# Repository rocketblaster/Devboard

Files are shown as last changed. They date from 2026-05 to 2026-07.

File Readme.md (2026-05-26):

# Development Board

## Description
This is a 47x35mm development board PCB made with a bare bones ESP32-C3. It can support wireless connections which is useful. It contanis three pin headers, with one containing power supply gpio. The other one is GPIO only and lastly the 2 pins are for TXD and RXD. Uses USB-C to get power. Boot switch and reset switch helps to activate anything using the chip. Chip enable can be connected via pins.

There's a red power LED near USB-C. Blue and green located on top for testing LED on top for testing LED. The case features pinout labels.

## Case

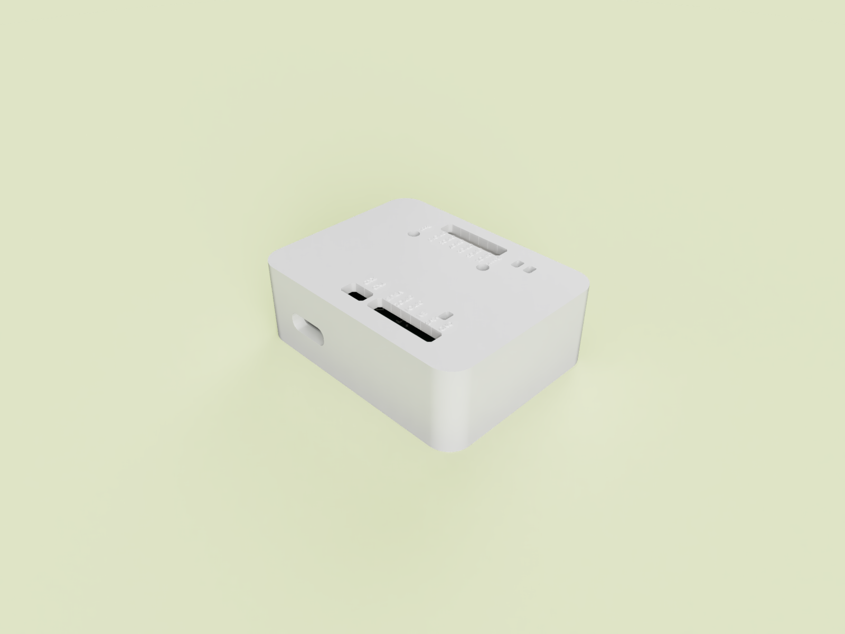
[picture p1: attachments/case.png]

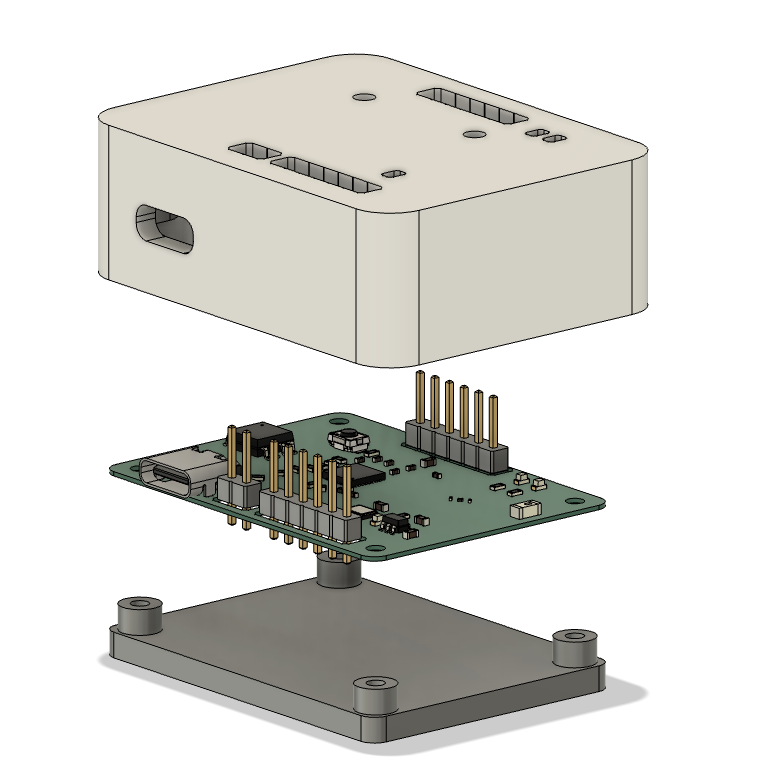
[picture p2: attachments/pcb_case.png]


## Demo Case

[3D case demo link](https://a360.co/3RtKpME)

## KiCanvas

[Demo Link](https://kicanvas.org/?repo=https%3A%2F%2Fgithub.com%2Frocketblaster%2FDevboard%2Ftree%2Fmain%2Fsrc%2Fkicad)

## Schematic

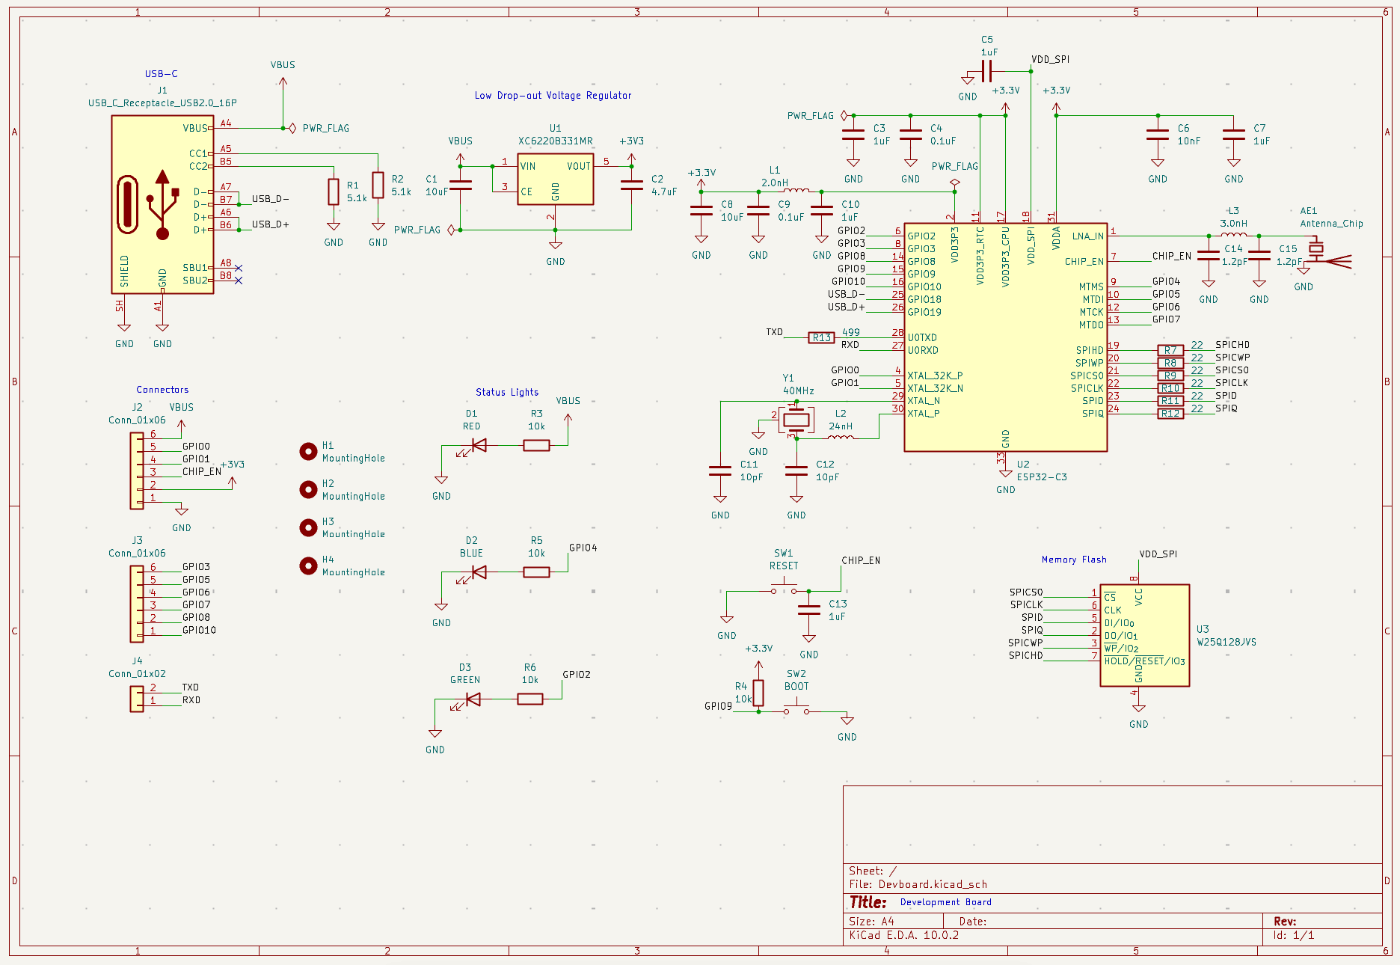
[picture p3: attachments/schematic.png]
Schematic


## PCB

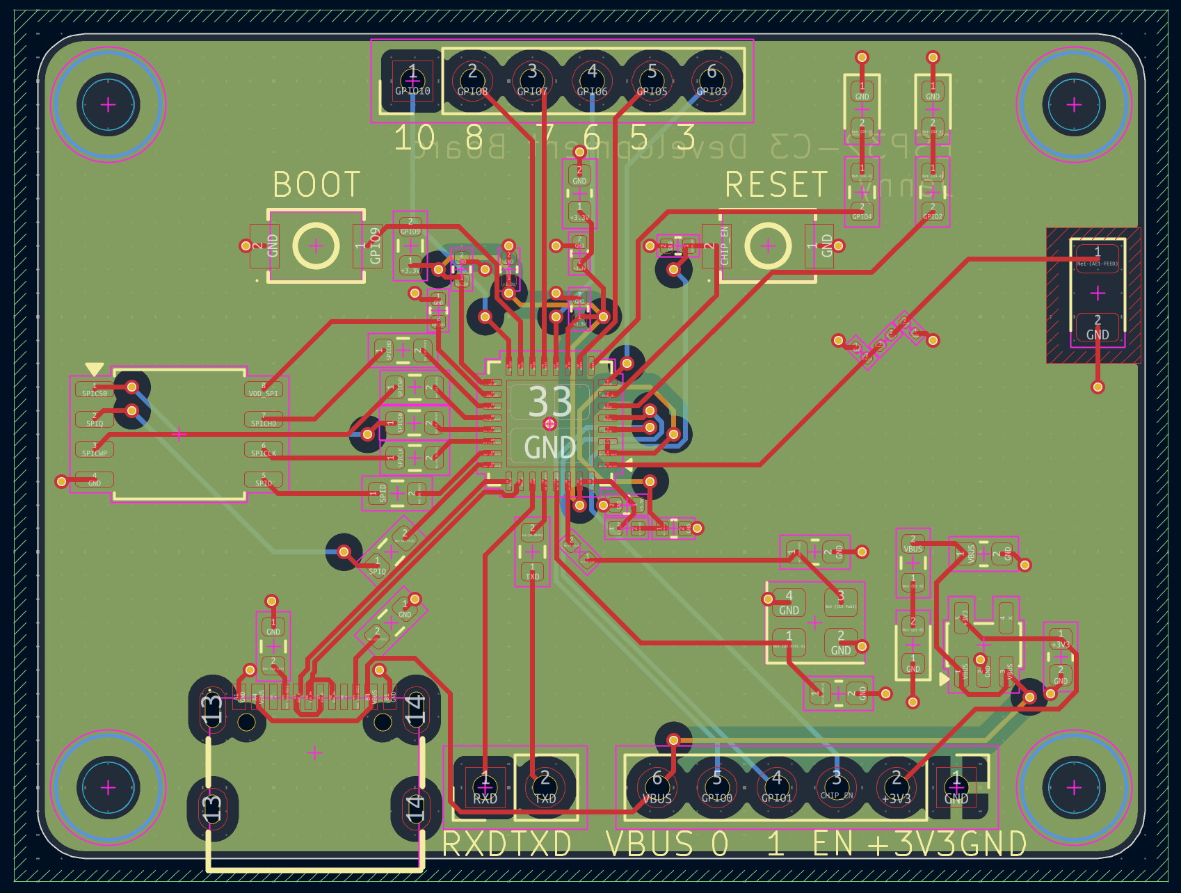
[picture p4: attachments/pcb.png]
PCB


## Render

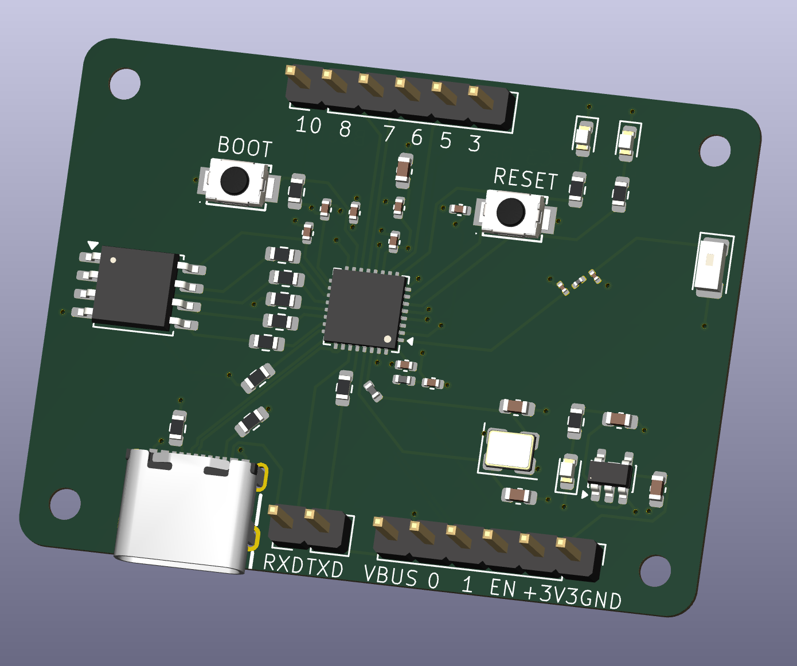
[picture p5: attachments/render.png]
Render


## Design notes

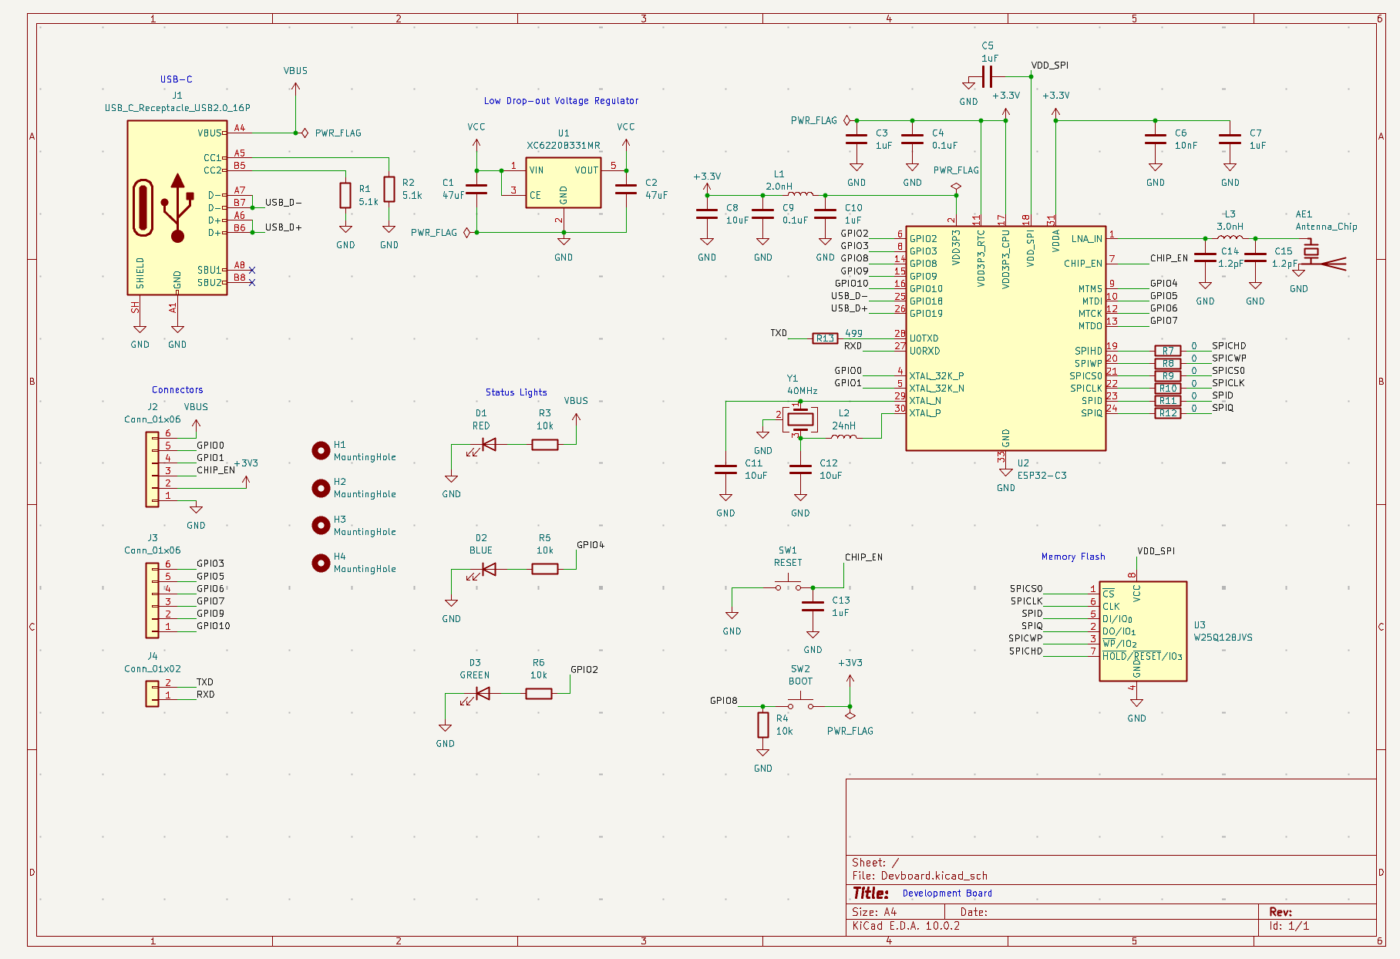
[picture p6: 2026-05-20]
attachments/schematic-v1.png

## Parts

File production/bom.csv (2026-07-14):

Designator | Footprint | Quantity | Value | LCSC Part #
AE1 | Johanson_2450AT18x100 | 1 | Antenna_Chip | C17192881
C1, C8 | 0603 | 2 | 10uF | C85713
C10, C13, C3, C5, C7 | 0402 | 5 | 1uF | C22399609
C11, C12 | 0603 | 2 | 10pF | C1634
C14, C15 | 0201 | 2 | 1.2pF | C21610742
C2 | 0603 | 1 | 4.7uF | C6119855
C4, C9 | 0402 | 2 | 0.1uF | C53084459
C6 | 0402 | 1 | 10nF | C60133
D1 | 0603 | 1 | RED | C19171390
D2 | 0603 | 1 | BLUE | C965807
D3 | 0603 | 1 | GREEN | C19273151
J1 | USB-C-SMD_TYPE-C-16PIN-2MD-073 | 1 | USB_C_Receptacle_USB2.0_16P | C2765186
L1 | 0402 | 1 | 2.0nH | C76769
L2 | 0402 | 1 | 24nH | C1012734
L3 | 0201 | 1 | 3.0nH | C2041469
R1, R2 | 0603 | 2 | 5.1k | C2907044
R10, R11, R12, R7, R8, R9 | 0603 | 6 | 22 | C2907129
R13 | 0603 | 1 | 499 | C23065
R3, R4, R5, R6 | 0603 | 4 | 10k | C2930027
SW1 | SW-SMD_L3.9-W3.0-P4.45 | 1 | RESET | C720477
SW2 | SW-SMD_L3.9-W3.0-P4.45 | 1 | BOOT | C720477
U1 | SOT-23-5 | 1 | XC6220B331MR | C86534
U2 | QFN-32-1EP_5x5mm_P0.5mm_EP3.7x3.7mm | 1 | ESP32-C3 | C2838500
U3 | SOIC-8_5.3x5.3mm_P1.27mm | 1 | W25Q128JVS | C179171
Y1 | Crystal_SMD_3225-4Pin_3.2x2.5mm | 1 | 40MHz | C379787

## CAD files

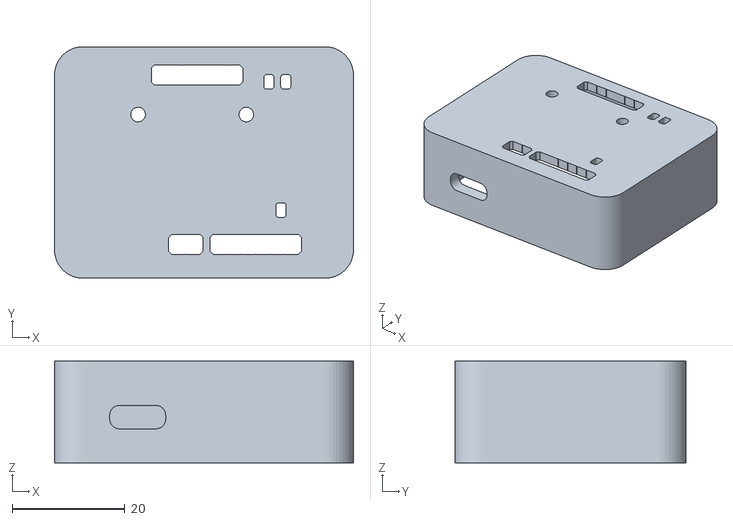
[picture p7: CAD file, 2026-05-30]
production/case_top.stl
53.0 x 41.0 x 18.0

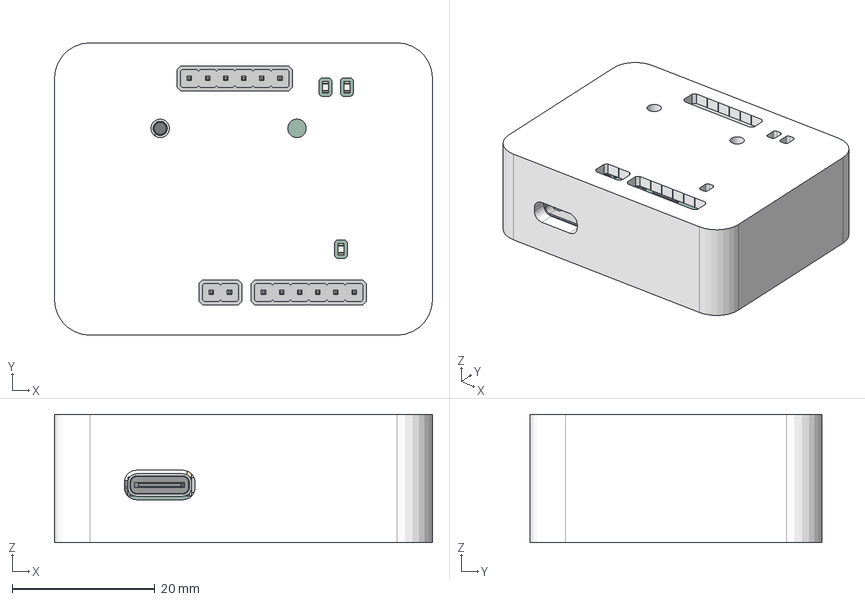
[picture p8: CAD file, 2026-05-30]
src/case.step
53.0 x 41.0 x 18.0 mm
R_0603_1608Metric_1 x 13
C_0402_1005Metric_1 x 8
L_0201_0603Metric_1
C_0603_1608Metric_1 x 5
QFN-32-1EP_5x5mm_P0.5mm_EP3.7x3.7mm_1
PinHeader_1x06_P254mm_Vertical x 2
L_0402_1005Metric_1 x 2
C_0201_0603Metric_1 x 2
USB-C-SMD_TYPE-C-6PIN-2MD-073_1
LED_0603_1608Metric_1 x 3
SOT-23-5_1
SOIC-8_5.3x5.3mm_P1.27mm_1
Crystal_SMD_3225-4Pin_3.2x2.5mm_1
PinHeader_1x02_P254mm_Vertical
Johanson_2450AT18x100_1
SW-SMD_L3.9-W2.9-H2.0-LS4.8_1
Devboard_PCB

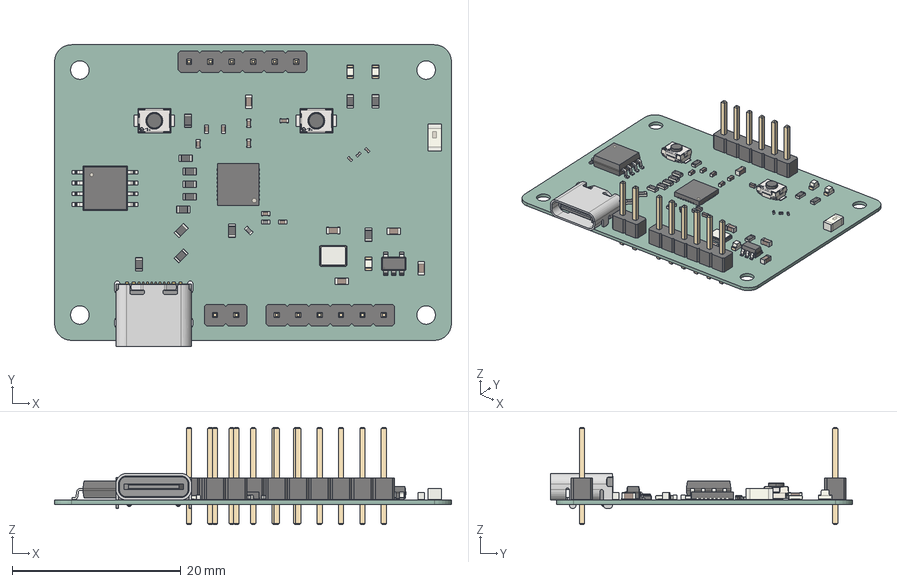
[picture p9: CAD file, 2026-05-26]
src/kicad/3D.step
47.0 x 35.7 x 11.5 mm
R_0603_1608Metric x 13
C_0402_1005Metric x 8
L_0201_0603Metric
C_0603_1608Metric x 5
QFN-32-1EP_5x5mm_P0.5mm_EP3.7x3.7mm
PinHeader_1x06_P254mm_Vertical x 2
L_0402_1005Metric x 2
C_0201_0603Metric x 2
USB-C-SMD_TYPE-C-6PIN-2MD-073
LED_0603_1608Metric x 3
SOT-23-5
SOIC-8_5.3x5.3mm_P1.27mm
Crystal_SMD_3225-4Pin_3.2x2.5mm
PinHeader_1x02_P254mm_Vertical
Johanson_2450AT18x100
SW-SMD_L3.9-W2.9-H2.0-LS4.8 x 2
Devboard_PCB

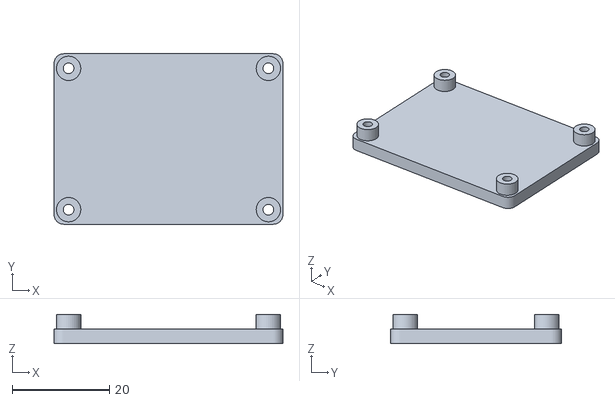
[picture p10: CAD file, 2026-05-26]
production/case_bottom.stl
47.0 x 35.0 x 6.00

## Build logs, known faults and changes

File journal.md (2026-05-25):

## May 10, 2026
I wonder what dev boards are useful for. What problems do I want to solve? Some features I would add is to make my development board aesthetically pleasing. For easier connectivity I'm going to add USB connectors. Since my computer is primarily USB-C I will use USB-C. Also usb-c is just easier in general. I need a one way usb-c with one way anything. With the intent of adding a case too eventually. I want to protect my devboard in someway. But that means I need to leave slots option for pinouts if I do add them. I think I will go with RP2040 for general purpose. But I need to make it unique in some way. It doesn't have wifi support though. Some applications I want to use my development board might include wifi, for example temperature readings or a wifi-powered clock from the cloud. I think I'll stick with the ESP32.

This ESP32 has an internal 8 MHz oscillator as I read through the datasheet for the ESP32 chip. It does not need an 8 MHz crystal oscillator then. however the addition of external crystal clock sources are typical 160 MHz. so I'm adding a 160 MHz crysal clock source. I picked esp32-d0wd-v3.

I am finding the external crystal clock oscillator I found this one [here](https://www.lcsc.com/product-detail/C43086214.html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)

I think this is unusually a high frequency for crystal oscillator though. I am going to recheck. Besides there's not a lot of stock. Ok I rechecked and it is crystal 40 MHz for wifi or bluetooth. I found another one. It is called [YXC Crystal Oscillators OW2EL89CENUXK7YLC-40M](https://www.lcsc.com/product-detail/C48888233.html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) A 4 pin crystal

Now i need a linear regulator between power and mcu which is ESP32. Maximum operating voltage is 3.3v. USB-C supports 5v. I am going from 5v to 3.3v. Uh I'll pick the XC6206 or related because it supports up to specific volts and I want a USB-C connector. There's other manufacturers but this part has more in stock, so more popular. [MSKSEMI XC6206P332MR-MS](https://www.lcsc.com/product-detail/C5252899.html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)

Ok I forgot about the current limits. I wonder if my ESP32 model needs to handle specific levels of current. I went back to power supply and it says

"The operating voltage of ESP32 ranges from 2.3 V to 3.6 V. When using a single-power supply, the
recommended voltage of the power supply is 3.3 V, and its recommended output current is 500 mA or
more."

I need an output current of 500mA or more on ESP32. The previously mentioned LDO is not compatible most likely. I found this one and I'm going to read the datasheet. [TDSEMIC XC6220B331MR](https://www.lcsc.com/product-detail/C22466451.html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)

It can support up to output of 300mA. For ESP32-C3 the current consumption in active mode for RF is peak 335 mA.

There are too many ESP32 models. Seems I'm looking for MCU specfically. I changed my mind. I pick the ESP32-C3 for wifi compatibility. I'm not intent to make a radio or anything. There is a specific data sheet so I will read it.

I found the hardware design guide. It says the power regulation be no less than 500 mA. This model I found works after some recommendations online. [TECH PUBLIC XC6220B301MR](https://www.lcsc.com/product-detail/C23378035.html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) I like that it supports up to 900mA and 6v.

### Time Spent: 2 hr

## May 11, 2026

So the LDO I want does not have a footprint in the kicad library. No worries, I found a better alternative! I'm going to use the [XC6220B331MR-G](https://jlcpcb.com/partdetail/TorexSemicon-XC6220B331MRG/C86534) because it can support up to 1000mA! That's more than what I need but you never know. Just in case. I'm going to import this into the KiCad library.

I'm going to add a crystal somewhere too. It seems the one I picked contains 4 pinouts. So I will import a symbol with 4 pins as crystal. Actually it's a 3 pin because one of the pin is a no connect. Also I am not sure where the mcu pinout is so I'm reading the diagram right now.

The document mentions about an analog pin called XTAL_N and XTAL_P which is connected to "external clock input/output connected to the chip's crystal or oscillator. P/N means differential clock positive negative"

And XTAL_32K_N and XTAL_32K_P for a 32kHz external clock input or output connected to ESP32-C3's crystal or oscillator.

I think I'm not going for the 32kHZ external clock because I have a 40 MHz crystal. Connecting it to XTAL_N and XTAL_P.

LDO pin I find out
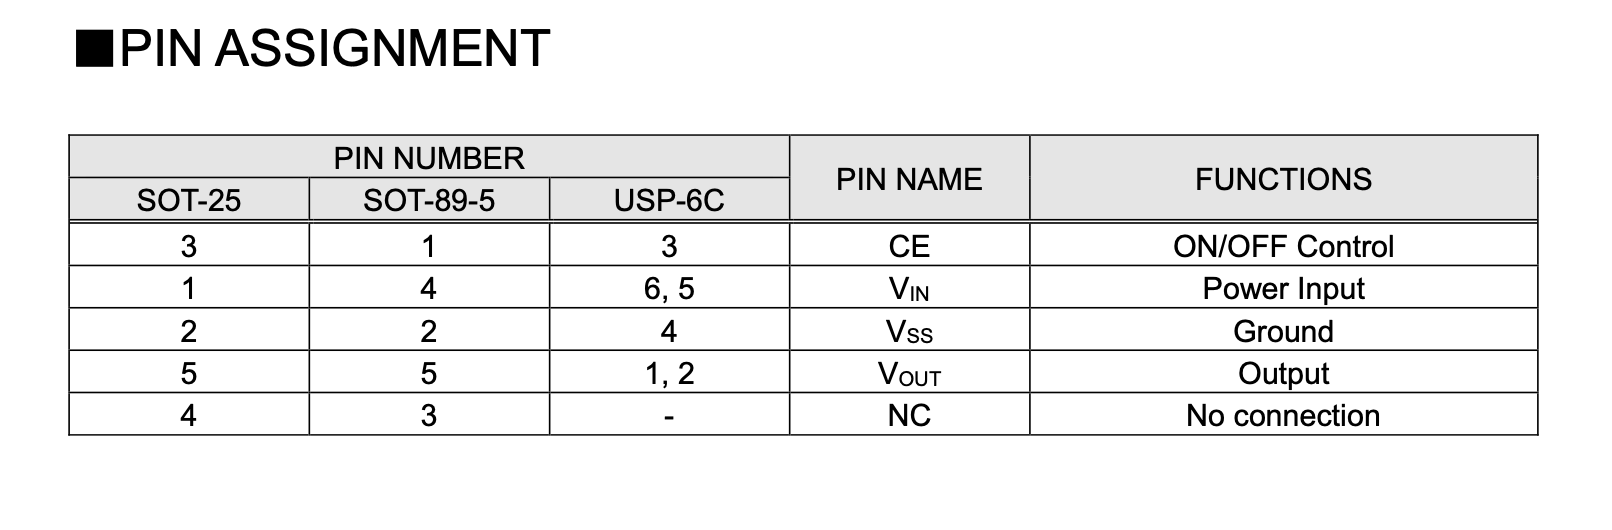
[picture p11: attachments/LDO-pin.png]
LDO pin


I don't know what CE and Vout goes to so I'll come back later.

Uh oh I read through the XC6220 and it's PCBA only. Come back later. Anyways I since the USB-C says VBUS I changed it to VBUS. I also have CC1 and CC2 but wired it to 5.1k pullup resistors as usual

My LDO needs capacitors to store some energy. I checked the data sheet and it says
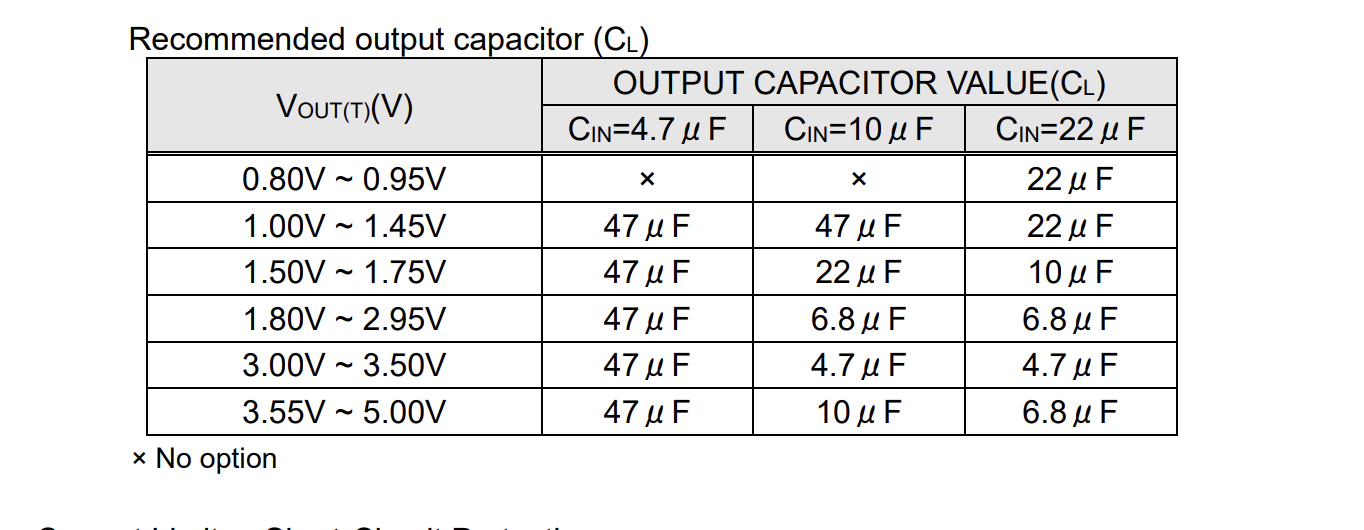
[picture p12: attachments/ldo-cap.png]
LDO cap


Maybe 47uF? Since it says voltage out. So I'm picking a 47uF capacitor then. But where does this go? After some researching, it seems my capacitor size depends on the crystal I have... I can 47 from what's recommended. It's hard to read. Datasheet wants a capacitor between VIN and VSS (ground). Same for VOut and VSS. Will also add somne net labels to the USB-C. I still have a CE pin left floating. It's an input pin. I will connect to Vin to keep it constantly on so it is open.

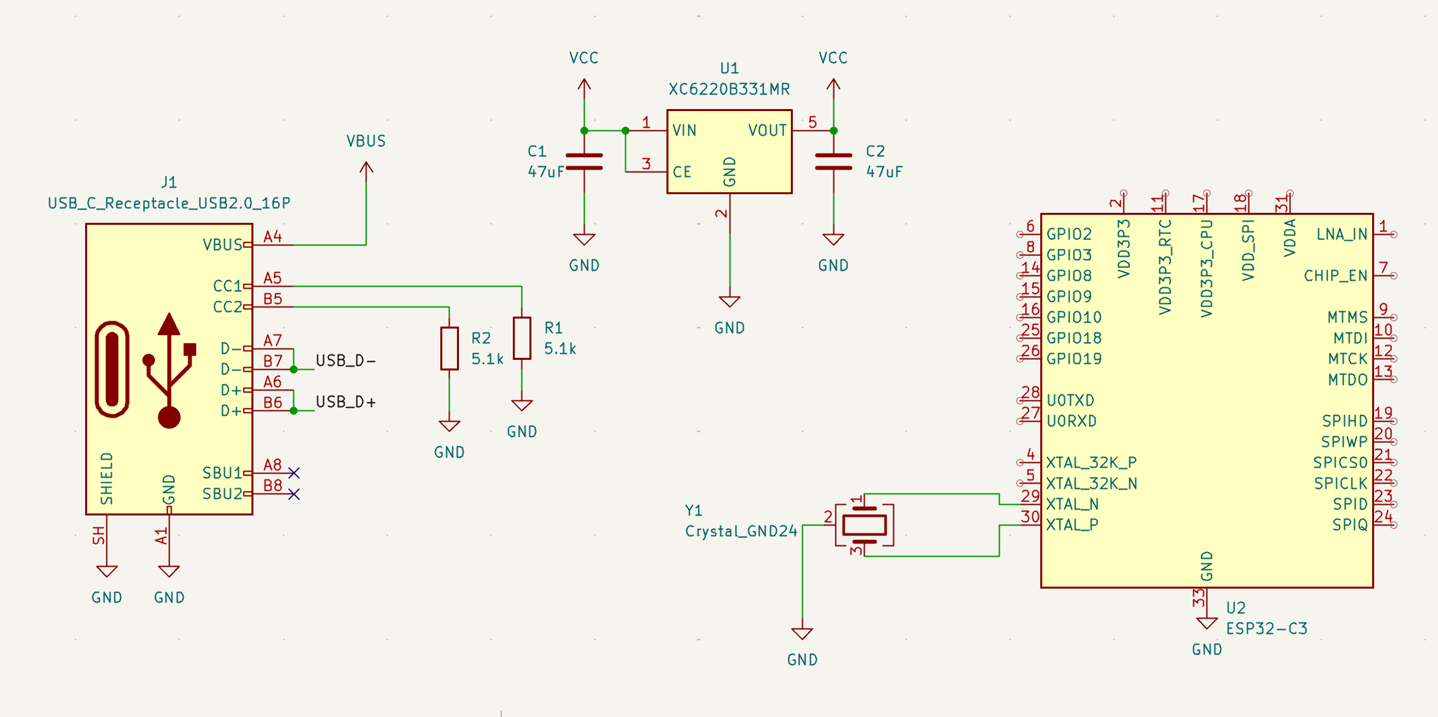
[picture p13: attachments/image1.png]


I'm moving on to the MCU. I have a lot of pins that start with V. Let's start by reading the datasheet and seeing what it says.

### Time Spent: 1 Hour

## May 12, 2026

Alright where I left off on was trying to wire up the VDD pinouts. So I'm going to read the datasheet.

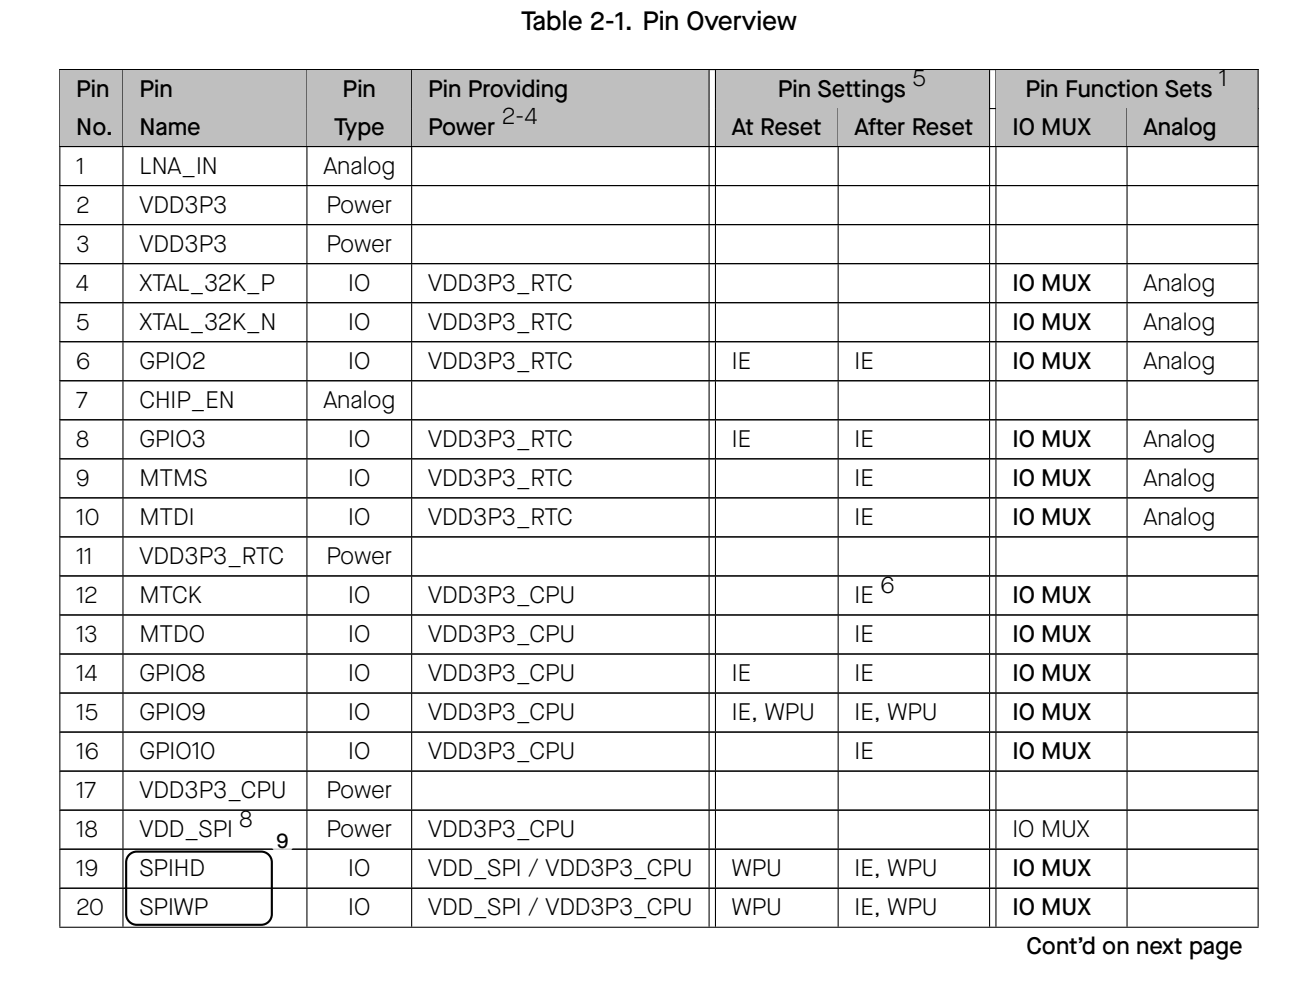
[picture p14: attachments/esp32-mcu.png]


I wonder if I need any capacitors. It is unclear in the datasheet but maybe it is because i am not reading deep enough. But I guess they're all connected to capacitors which lead to ground. I'm following the hardware design schematic guide from the docs. I am told to connect 0.1uF or 100nF capacitors.

"When using a single power supply, the recommended power supply voltage is 3.3 V and the output current is no less than 500 mA.

It is suggested to add an ESD protection diode and at least 10 μF capacitor at the power entrance."

I am going to add a 10uF capacitor at the power entrance. I don't know what to do with VDD_SPI, a digital pin. It seems it wants to connect a 1uF to ground according to the datasheet. I'll just follow it. Then I rename my designator labels so the numbers read left to right.

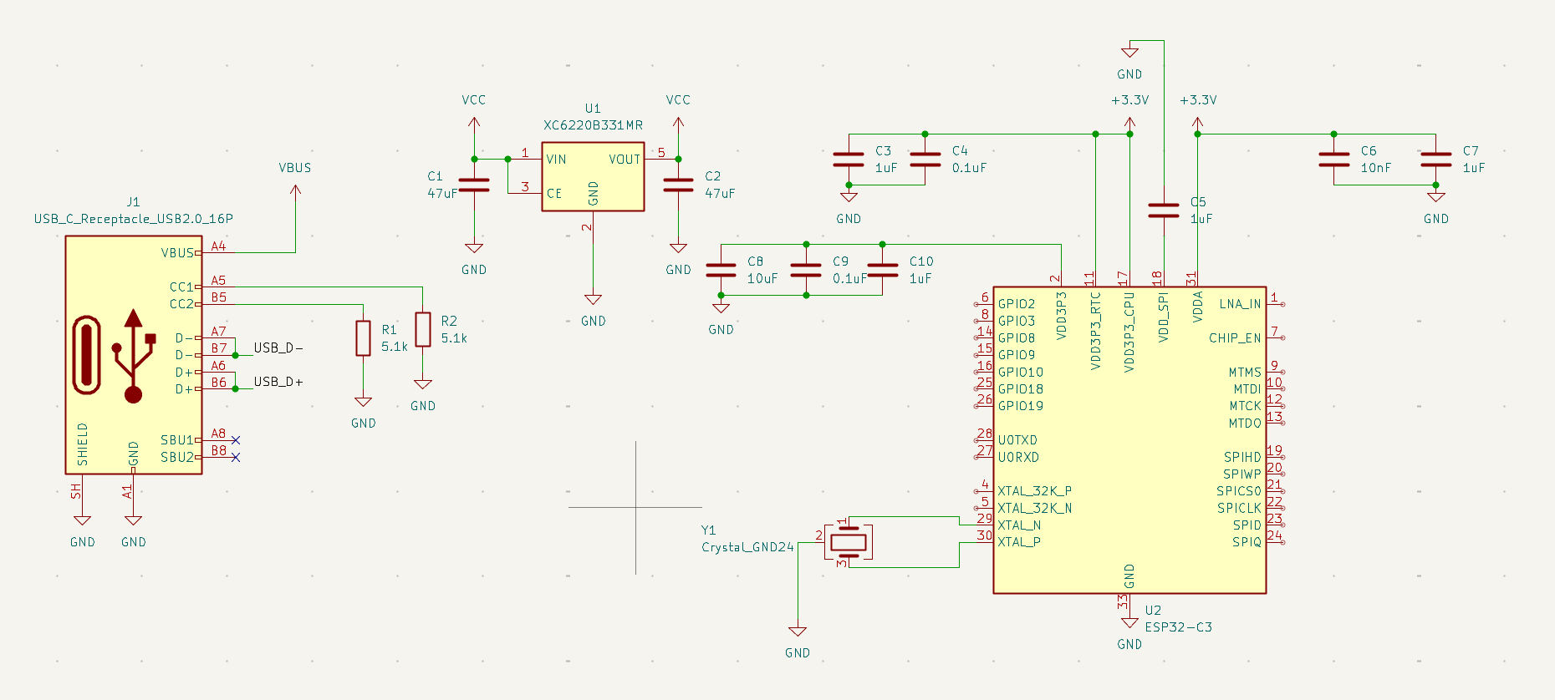
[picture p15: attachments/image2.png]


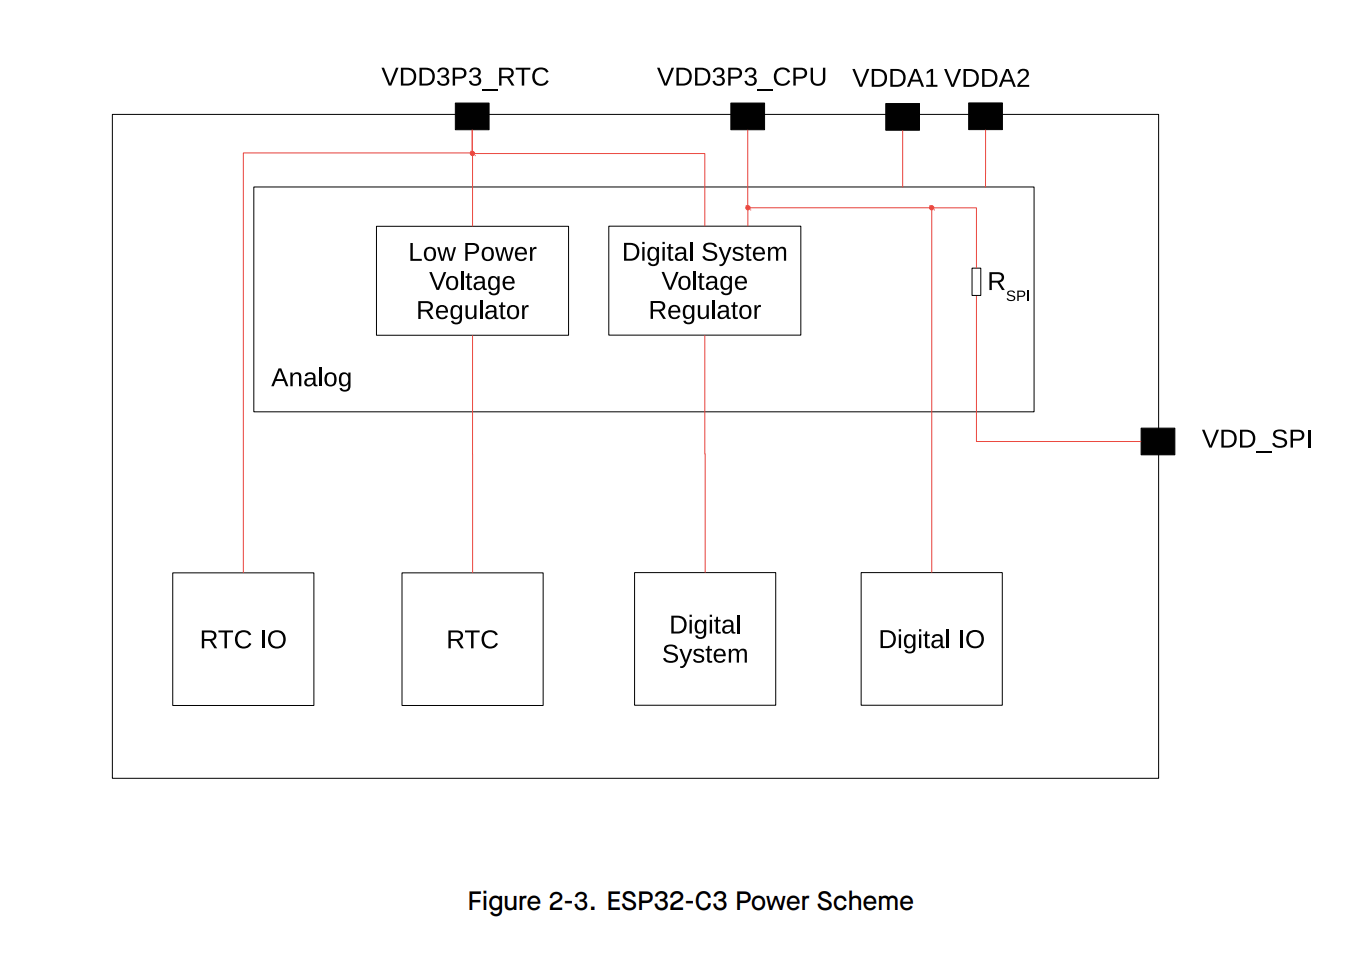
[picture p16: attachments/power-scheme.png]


Oh also I found a better crystal. The one I originally found did not support 10.0ppm but this one does as it is also 40MHz. It is called [YXC Crystal Oscillators XL2EL89CPI-111YLC-40M](https://www.lcsc.com/product-detail/C5444549.html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)

Its load capacitance is 10uF or 20uF
Maybe I will try a 10uF.

C = 2(10-5) C

Just in case, and I end up with 10uF capacitors each. Next, some research of the docs told me to connect the USB D and N pairs to GPIO 18 and 19. I still need to figure out how the decoupling capacitors works... Moreso of its organization. i'll figure the rest of the pinouts in the next day.

### Time Spent: 1 Hr

## May 15, 2026

I wonder what I should add to my development board. I'm going to creaate net labels for the rest of my schematic. The ESP32-C3 has a couple of switches, I wonder what it does. So I'll add switches, status lights and connectors. To make it different from my guided tutorial, I will change the shape and silkscreen slightly.

GPIO is programmable pin outputs. This means I could program the ESP32 and change GPIO1 to be the swtich button or something. So any GPIO pin can be a feature I can add on the board. But there are specific pins as said here

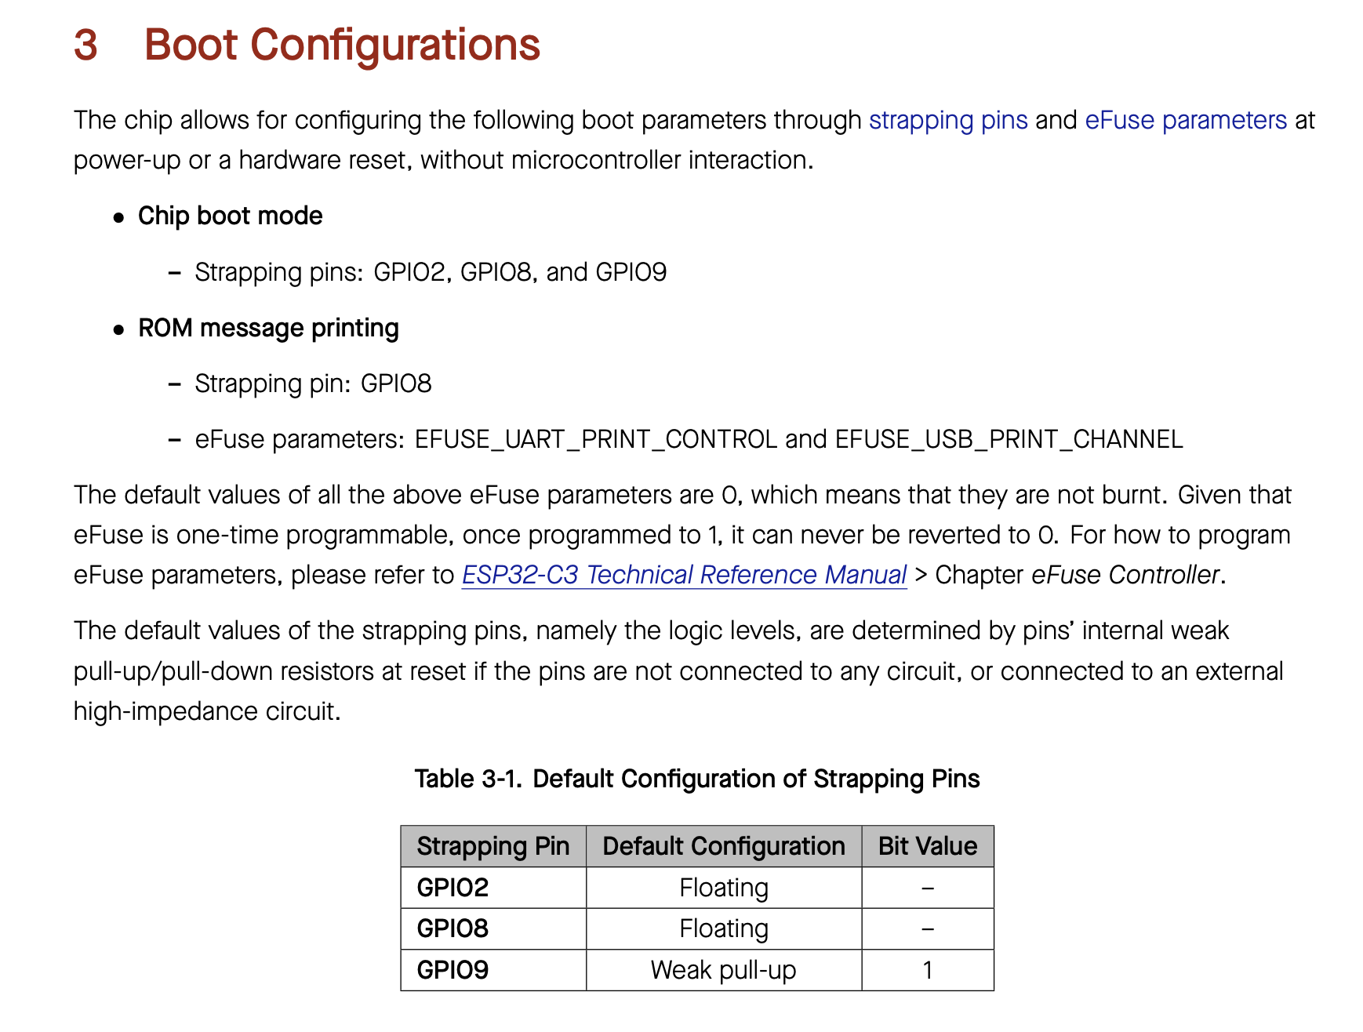
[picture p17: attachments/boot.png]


Boot needs a weak pull up resistor so I'm adding 10k ohm. For reset I'm going to add a capacitor of 1uF just to be safe. I am going to create net labels for UORXD and UOTXD. They stand for Receiver and Transmitter respectively. Yeah I'm not sure what to connect it to. For LN_IN that is a radio. I don't have a use so I'll just give it a net label. Maybe I will try to termiante it. No it goes to an antenna. I will add one. I am following the schematic diagram right now. The SPI pins are like flash. I'm adding net labels because the resistors make it look unorganized.

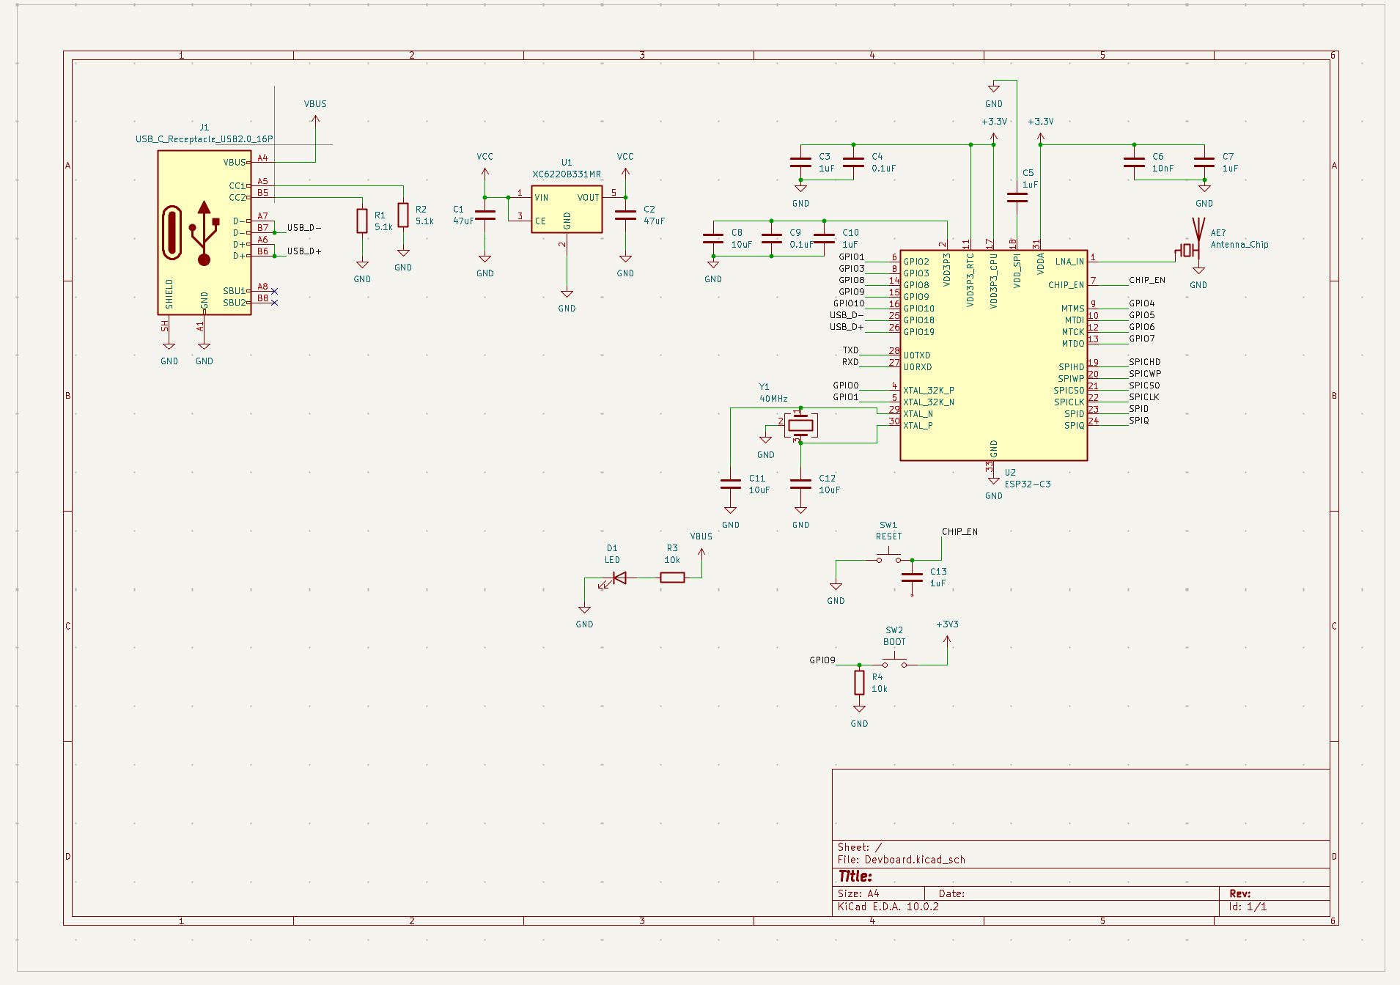
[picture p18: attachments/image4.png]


Seems like CHIP_EN is some sort of reset pin. This function of the pin is "High: on, enables the chip (powered up).
Low: off, disables the chip (powered down).
Note: Do not leave the CHIP_EN pin floating"

Some sort of power pin I suppose. I wonder if I need multiple status lights. I'll do two, since this is a small LED. The configuration I have for the LED seems unusual, so I will change it. I will leave one connected to VBUS as an indicator of it being turned on. Maybe one for blink effect too and it'll be blue. It'll be connected to a GPIO pin, wonder which one is open. If space allows, I'll add a green one! I connected the LED to GPIO8.

I noticed a flash when referencing the hardware design guide. I am powering it through USB-C so i dont think I need a flash. I'll still add it just in case. This particular part I picked was from research and it supports 128 something. I'll probably use that much lol

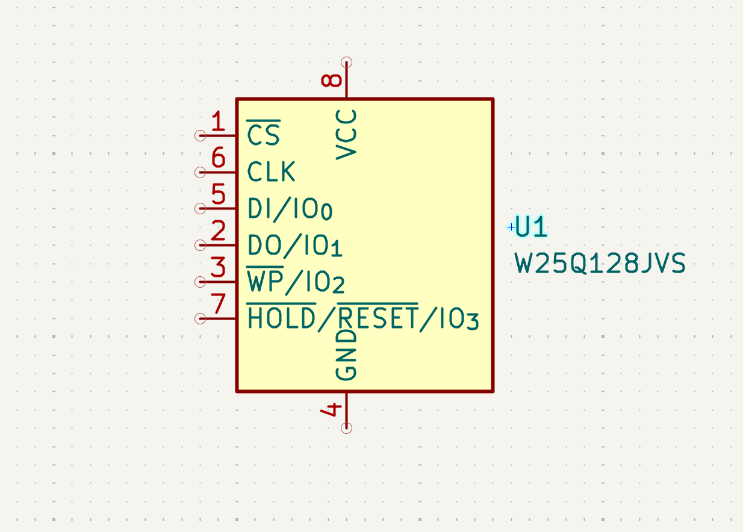
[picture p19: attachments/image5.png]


I'm removing the VDD_SPI whatever I put on there. Stil adding a capacitor to stablzie signals. Design gudie says 0 ohms, but another person put 100 on theirs. I'll probably do 0 ohm for mine because it is flexible. ugh but schematic gets crowded. Well I figured it out, I place it real close on the wire lines.

Now I need to move on to whatever's left for the schematic. How many connector pins do I want on my development board. How many pins do I have to connect? Would I put all my pins to one side or on both? Doing male headers because they're more durable and stack some jumpers on top too.

I guess I will add inductors because I cannot omit them as a bare bones chip. The values for RF Antenna is too be decided by the actual PCB traces, and the crystal I must calculate. I think 24nH is an ok value for inductor.

Still thinking about the connectors. I think I have GPIO0, GPIO1, GPIO10, GPIO4, GPIO5, GPIO6, GPIO7, TXD and RXD open. I need to include a place for 3v3 and GND as well. So that's about 9 slots plus 2 more which is 11. Maybe I'll add one more option for VBUS as well. I know there is 5v option but it needs to go downscale in volts... I guess I'll do a lopsided amount of connectors then. GPIO8, GPIO3, GPIO3 are used by the diodes. A symmetrical pattern. Oh! also for boot and reset pins too. Added those! Now it fits.

Wooo here's the schematic so far! I did a lot of organization mostly though. Waiting on specific values for PCB.

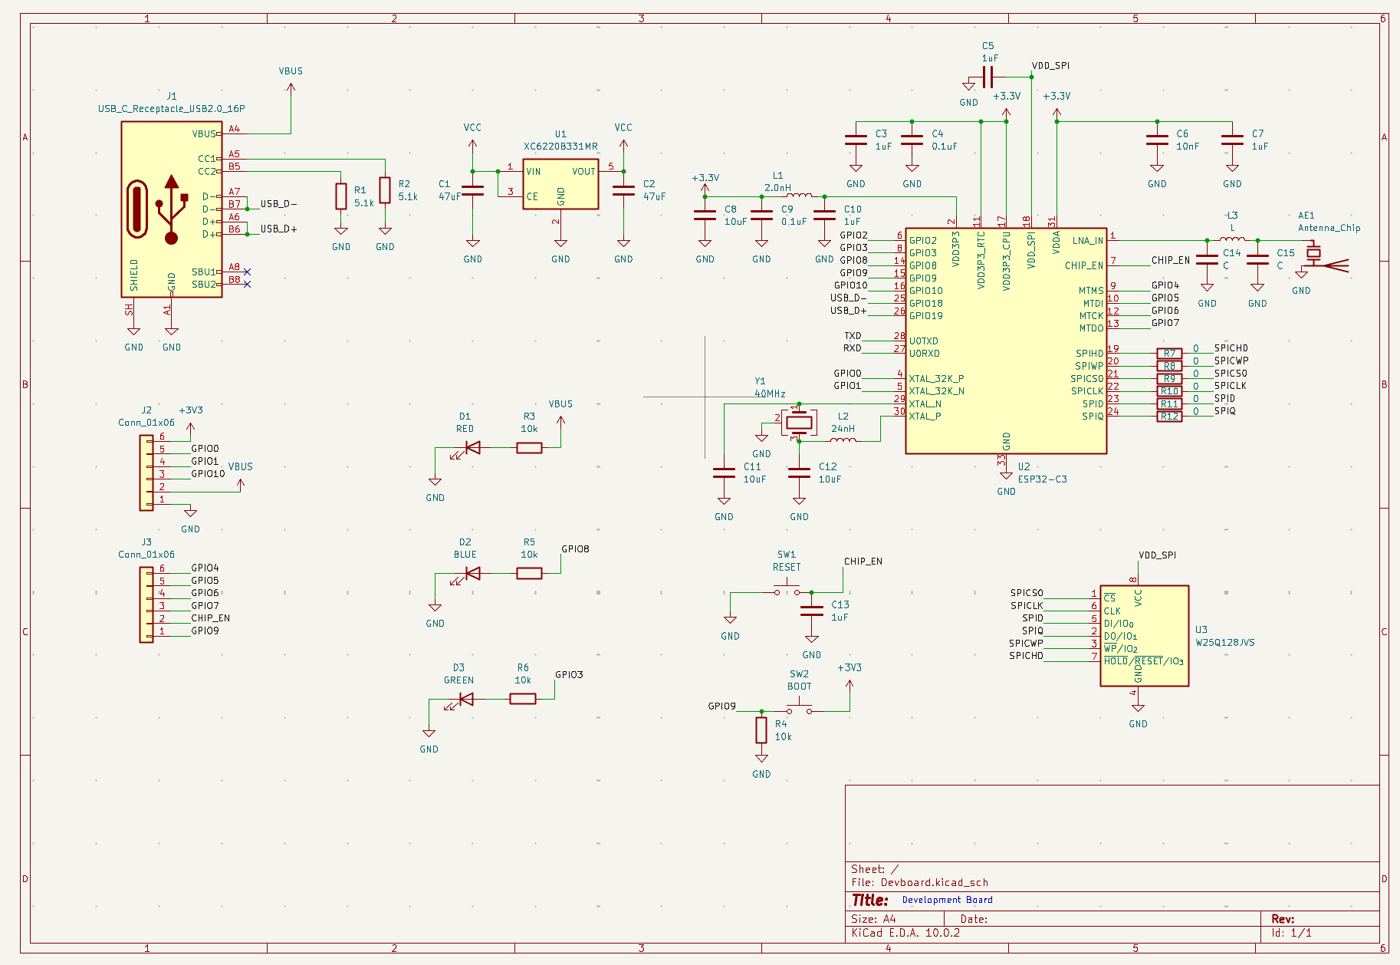
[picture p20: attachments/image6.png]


### Time Spent: 2 Hours

## May 16, 2026

I am getting to work by adding power flags. I wonder what shape my PCB should be. Why does my GHND have no input power pin. There seems to be 15 open total pins but I only have 12 at the moment. Adding one more set of connectors. Just want one power source. Then I want four mounting holes. Now I need to assign footprints. I'm going with 0603 footprints because they're simpler to solder. For RF_Antenna footprint I searched it up and it says there are many types. I'm thinking of going with a ceramic antenna since my module may be small. But I'll check the docs just in case. Probably a Johansen connector chip. For mounting holes I'm going with m2 screws because they're most accessible and in between. I need to transfer footprints over.

Spent forever trying to import the easy eda USB-C aghh. figured it out by running python script path and command. Assigned usual footprints. Not sure for mounting holes, buttons and the inductors. I guess I will go with the usual footprint for a button. It looks like 6x6mm is the standard but is not in KiCad by default. I'll use 0201 or 0603 for the inductors. I'm going to use the part number C720477.
Okay i got all of my footprints besides the mounting holes lol.

### Time Spent: ~1 Hour

## May 17, 2026

Adding mounting hole footprint finally. I import them all into the PCB. Now I create a 100mm by 100mm square. Well it has to be under. I'll try a rectangular shape and experiment with board outlines. Mostly filmed on lapse. Need some capacitors to be close together. Also I think it is best to hide silkscreen... Dev boards dont really need silkscreen labels. I have a feeling I want to swap GPIO 10 and CHIP_EN, and swap 3v3 and VBUS because of overlapping ratlines. Ugh I should've picked pins that are next too each other. I'm switching out GPIO8 for something else. Switch to GPIO9 with the boot switch. Then GPIO9 I will swap for... GPIO4 works. Doing a lot of swapping and making sure there aren't duplicates. Not sure for this extra pin connector... I have an extra slot.

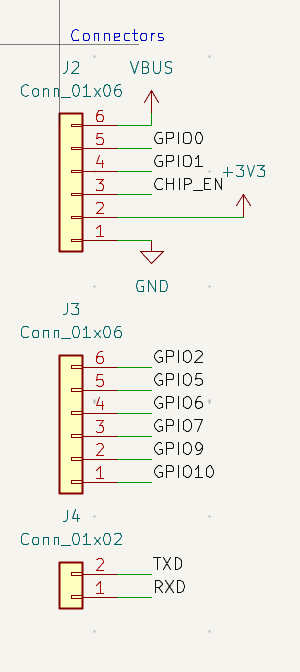
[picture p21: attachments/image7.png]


Probably will leave an extra anyways. For the memory flash I think vias are my only option. Perhaps I should go for a 4 layer board. I'll read through the design guide. Forgot to give UATXD a resistor! I need to place my resistors close to the ESP32-C3 for the flash. Definetely need vias and they're ok! GPIO pins last.

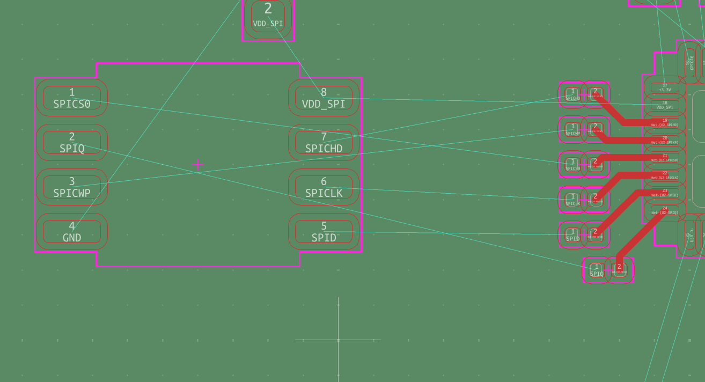
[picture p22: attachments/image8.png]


My crystal footprint is giant. The correct package is SMD3225. I'm routing all my power supply on the third layer! With some exceptions. I need to keep the RF and Crystal clean of anything underneath as well.

had to swap some values too liek GPIO because of the ratlines on the schematic.

I hate how I have so many vias. Cant do anything about it. AAAAA And my traces are all weirdly long. I just need to get rid of the silkscreen value designators now. Oh I also need labels for pin headers. Next time...

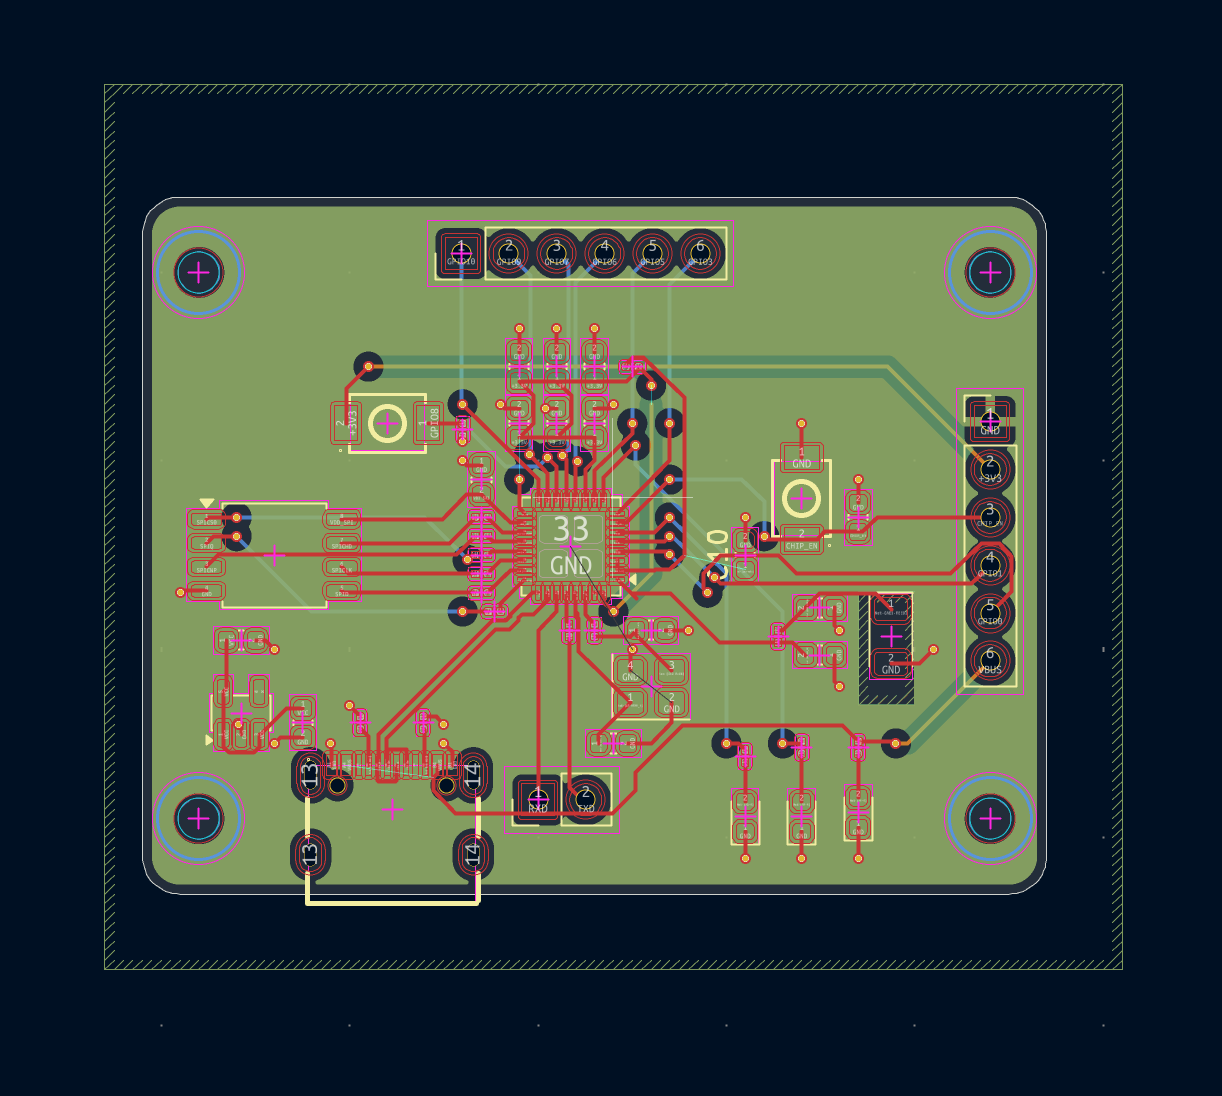
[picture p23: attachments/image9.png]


### Time Spent: 4 Hours

## May 18, 2026

Development board here... So close. I added some silskcreen labels and credits to myself for making this cool awesomesauce development board. Would like to add graphics but I'm not feeling it. I put my silkscreen on the top because I want people to see it as form of accessibility. Oh DRC I need to fix the clearance errors. I am searching up JLCPCB clearances. Uh i realized some pads are overlapping. Ok net classes set to 0.09mm clearance as said my JLCPCB. How do I un clear the clearance on my USB-C? Some items forgot to connect so I'm rerouting some areas. It's time I ignore the pad errors from DRC. Now I want to update my GitHub Repo to make it polished! Sparkles!

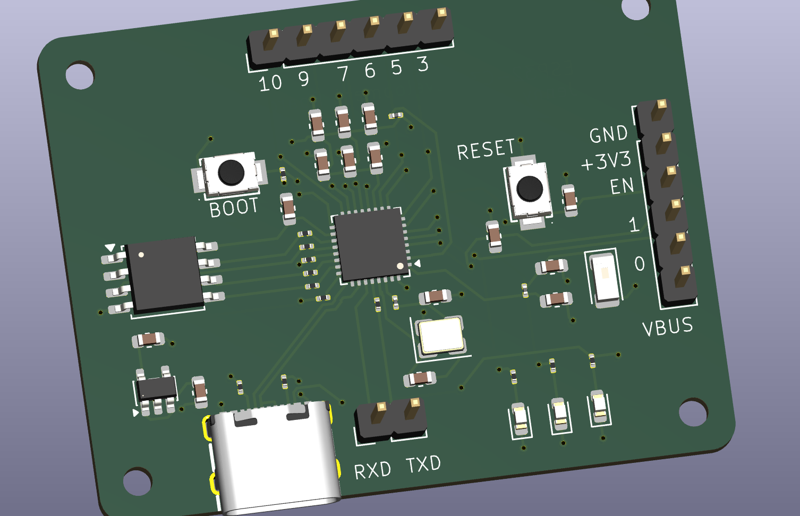
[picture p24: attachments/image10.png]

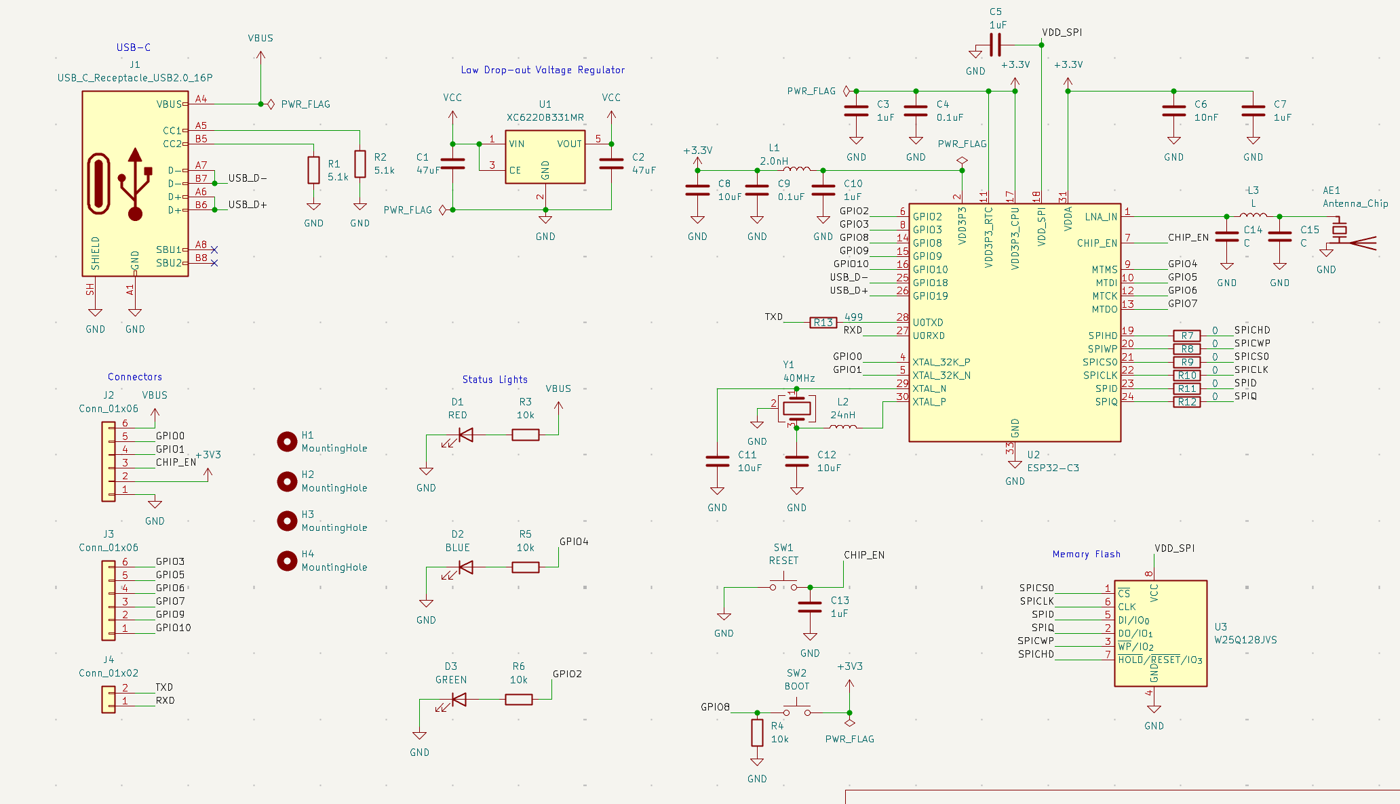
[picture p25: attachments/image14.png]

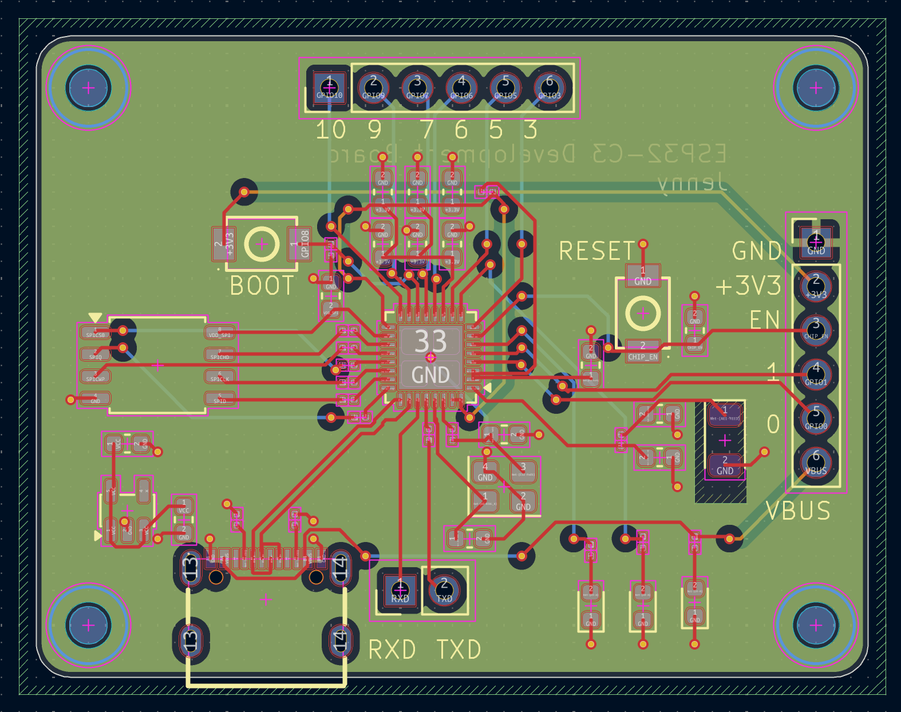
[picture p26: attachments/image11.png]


I can see a few maybe unruly routing. But I'm rushing to get this done so I can do homework! I need freedom. I think it still works fine hopefully. One more thing, crystal be in the keep-out zone. So I added it and rerouted some vias too.

Need to work on my BOM next. For mounting hole and Pin header im not going to include them becasue I know a place where to get pin headers. My antenna im not sure i have to look it up. RF components need to be 0201.

Oh wait i still need to calculate the values for c14 and c15. Maybe I will go with L3 value is 2.4nH, both C14 and C15 will have a value of 1.2pF. Just needed to pick something but it is also within range.

47uF C140782
1uF C15849
0.1uF C15849
10nF C100042
10uF C96446
1.2pF C85895
RED LED C19171390
BLUE LED C965807
GREEN LED C19273151
Type-c C2765186
2.0nH C86125
24nH C49247134
3.0nH C98044
5.1k C2907044
10k C2930027
0 ohm C100044 (1%)
499 ohm C2933227
buttons C720477
LDO C86534
ESP32-C3 C2838500
Memory flash C97521
crystal C5444549

Ok that should be all I typed in. Now I find an antenna that works. It has to be 2.4GHz and I found a 1206
SO rf antenna C293767 means I have to change footprint. Doesn't seem to fit what is in the library currently. Come back later

### Time spent: 2.5 Hours

## May 19, 2026

Part number C89334 for the RF seems good after some specific keywords. Kept same footprint because its is 2.4GHz OK BOM is done. I also changed up the PCB too. Ok what's next? I hope I'm done. Uploaded it and BOM exports fine! I now need to organize my GitHub. Somehow my fab toolkit got uninstalled.

### Time spent: Probably 30 minutes.

## May 21, 2026

My project is missing many key variables. The feedback included
- No routing ground, use via instead
- Use one via per pad
- Impendence match RF antenna
- Relayout RF antenna placement using the design guide
- Dont use 0 ohm resistor
- Crystal does not need keep out zone
- LDO wired incorrectly

I want to work on rerouting some regions though. I have a place where my I have more than one via per pad. The 0 ohm thing is only the footprint. Maybe I'll pick a 22 ohm resistor then as recommended as mentioned in the guide for 0 ohm footprint. Or no. The footprint is whatever matches. Oh and adjust my RF antenna capacitor and inductor values!

First I'll get started on removing any places where I routed ground. I did it for the crystal and removed keep out so it's been changed. Changing how I wired up the LDO means I'll have to replace my components. let me focus on the LDO wiring as well as changing from 0 ohm to 22 ohm. For the LDO im going to copy the schematic diagrams then.

The data sheet for XC6220 mentions
CE is on/off. So input. Chip enable.
Vin is power input
Vss is ground
Vout is output
NC is no connect.
I also need load capacitors. Some 10uF. Then load from Vout. I still keep 47uF for load most likely. I have Type B so CE doesn't have pull-down resistor but it has C Load discharge. I will add a pull-down resistor. My Vin is the input, so from USB-C and output should be 3v3. I still want to keep my LDO on so I'm connecting CE to Vin. Because CE uses input voltage to determine if it is on or off. I've already connected Vbus to it so it is ok. Then Vout leads to another 10uF capacitor and a load so my ESP32-C3 somehow. I picked 47uF for my load. But I'm using 10uF so I guess I'll switch to 4.7uF for my output according to the datasheet. Also these components on the PCB need to be close to each other. I see the +3v3 goes to the VDD3P3, just through net flags. Uh oh. I have two voltage powers pins connected let me fix that. That's the only diffeence from my original, so I have no idea what was even wired incorrectly. Capacitors have to go to ground too becasue the datasheet said it is between Vin and Vss.

I will change where Boot connects to now. It goes to ground with a pull down resistor too. I think I will change GPIO8 to GPIO9. And and change footprints! For 4.7uf footprint it'll be C19666

As for the flash lines, I will replace the 0 ohm resistor with 22 ohm becasue of USB-C pairing. I'll go with part number C23345. Ok it's been changed. I think that's all for the schematic. There's alot to be changed...

I now want to move everything! Let me relocate boot, reset, and the pin headers containing 3v3 and vbus. Focus is to have optimal placement of RF antenna. Says to use 0201 which I should have. Needs to be close to the antenna in a zigzag. I'm going to need a ground stub for capacitor. RF trace should be routed at 135 degrees. Do not route traces underneath RF trace and no high frequency signals routed close. Stay away from USB, USB serial, and UART signal lines. UART should be surrounded by ground copper and signal vias. Connect stub via third layer. Need a 50 ohm impendence. Follow the table provided. Ok maybe my layout is too pour because I keep having to route traces underneath it ahhhhh

I am thinking of adding an esd protection diode, I'll wait until i can route though. Maybe my power supply needs some work on placement. It says to add 10uF capacitor before the power trace enters the chip. I will put it near chip then.

Power supply for pin 2 and pin 3 are RF related. so I need to place a 10uF capacitor for each pin OR 0.1 or 1uF cap in parallel. I have those! Near pin2 and 3 I need to add an CLC or LC filter ciruit contianing an inductor to supress signals. Recommend to use 0201 components except for 10uF. Change footprints now then oof. also LCSC part number. Except for LDO. Now they're all small. GPIO pin to headers are done last.

The chip ground needs to have at least 9 vias. I wonder why. Add later. At least two vias is ok for power supply it says.

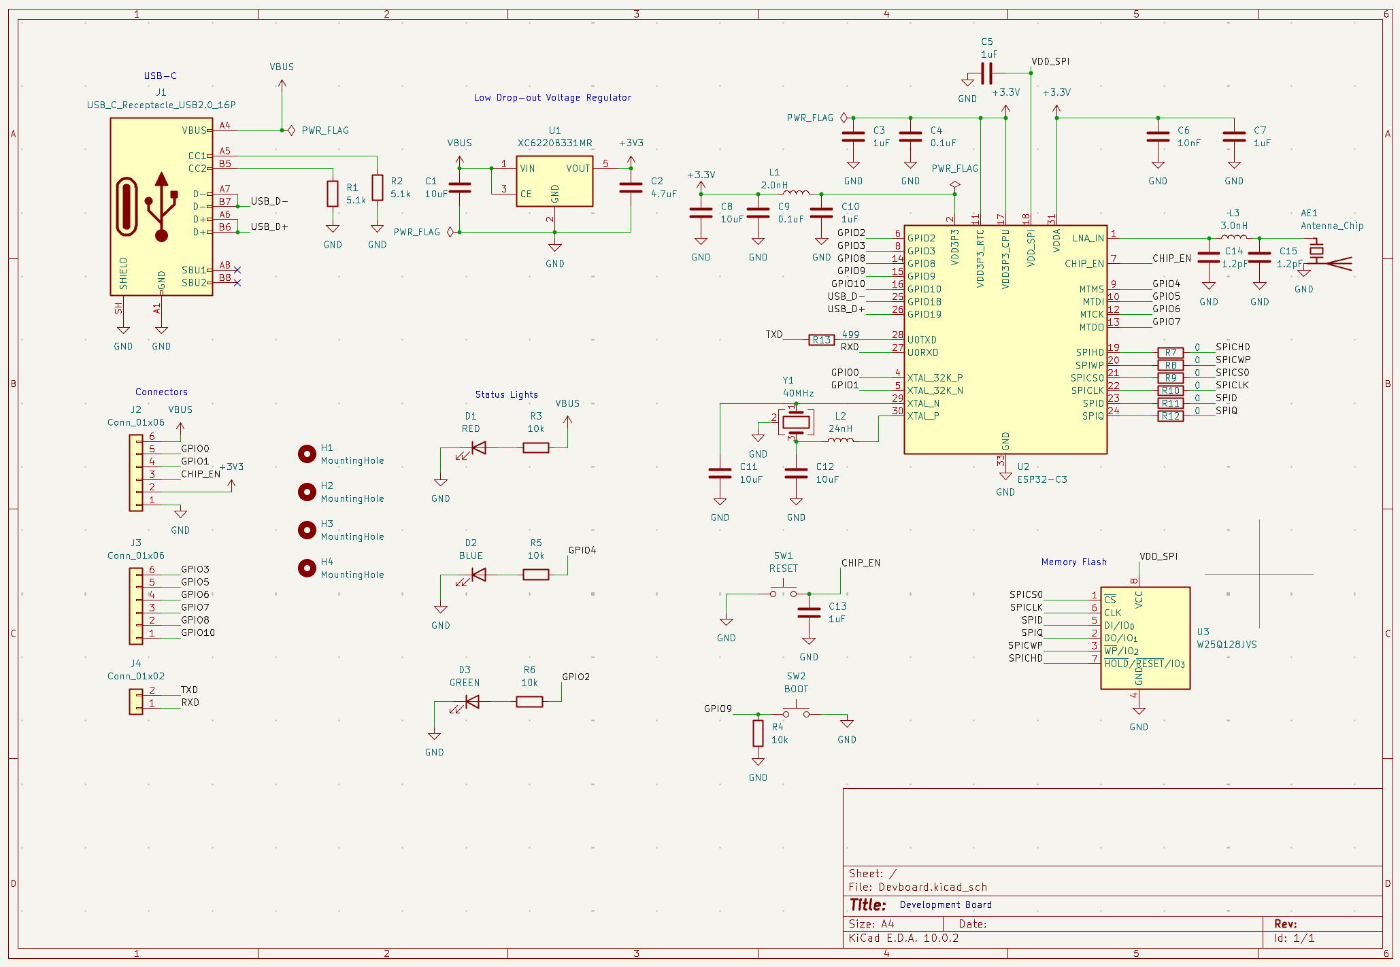
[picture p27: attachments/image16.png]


### Time Spent: 1.75 Hours

## May 22, 2026

I think the pin header needs a big overhaul sad

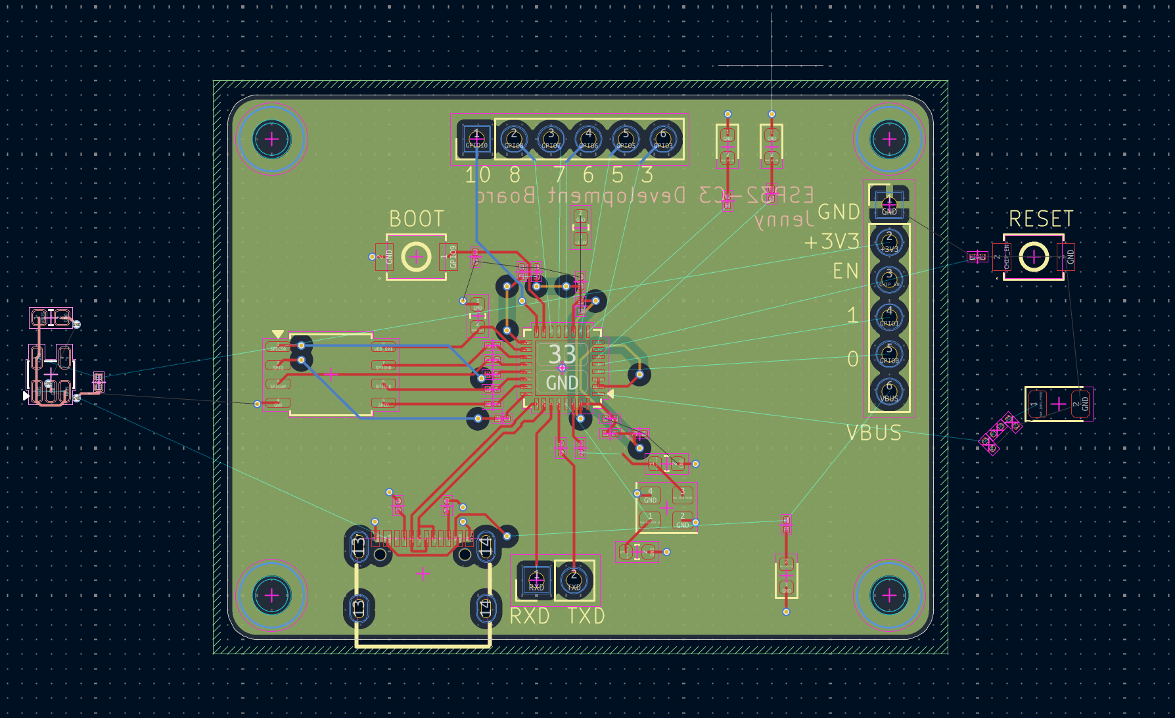
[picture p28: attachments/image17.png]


Now i can I add the labels without forcing my crystal to move closer to my RF antenna. Simply have to move onto backside. also now I have to round around RF trace. LN_IN i guess.

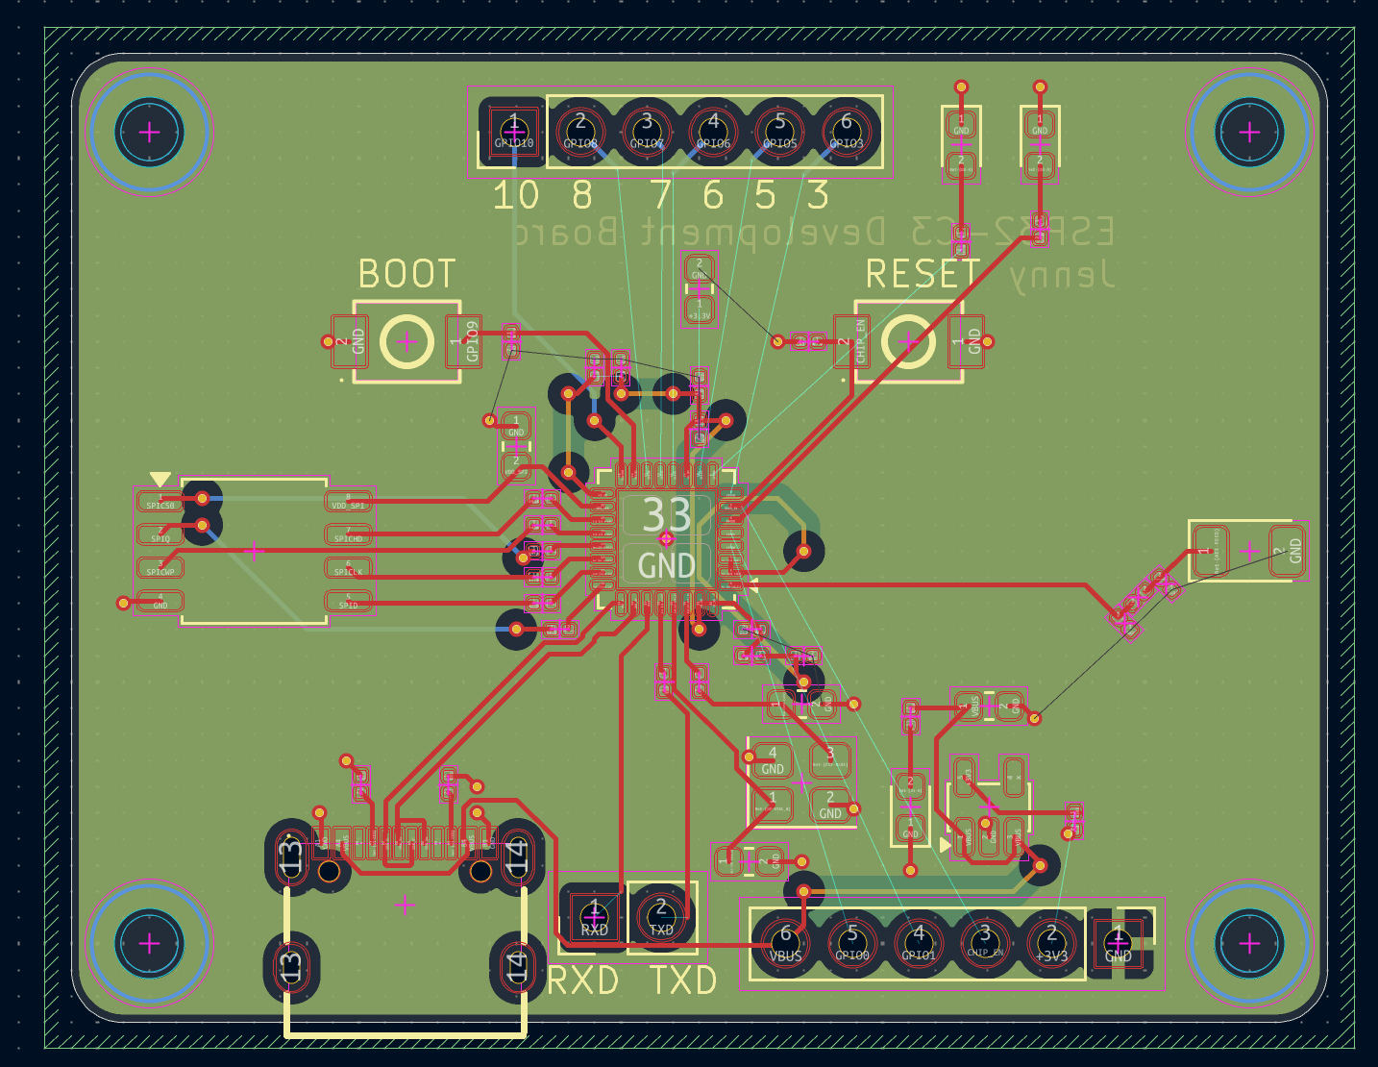
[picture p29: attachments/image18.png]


Yeah I got it somehow. This is ok! I think so? no overlapping traces under RF antenna. Most worried about crystal oscillator. I don't see any traces underneath so it is fine. The labels do fit! Ok I was worried. Also I rerouted everything so nothing goes under the antenna.

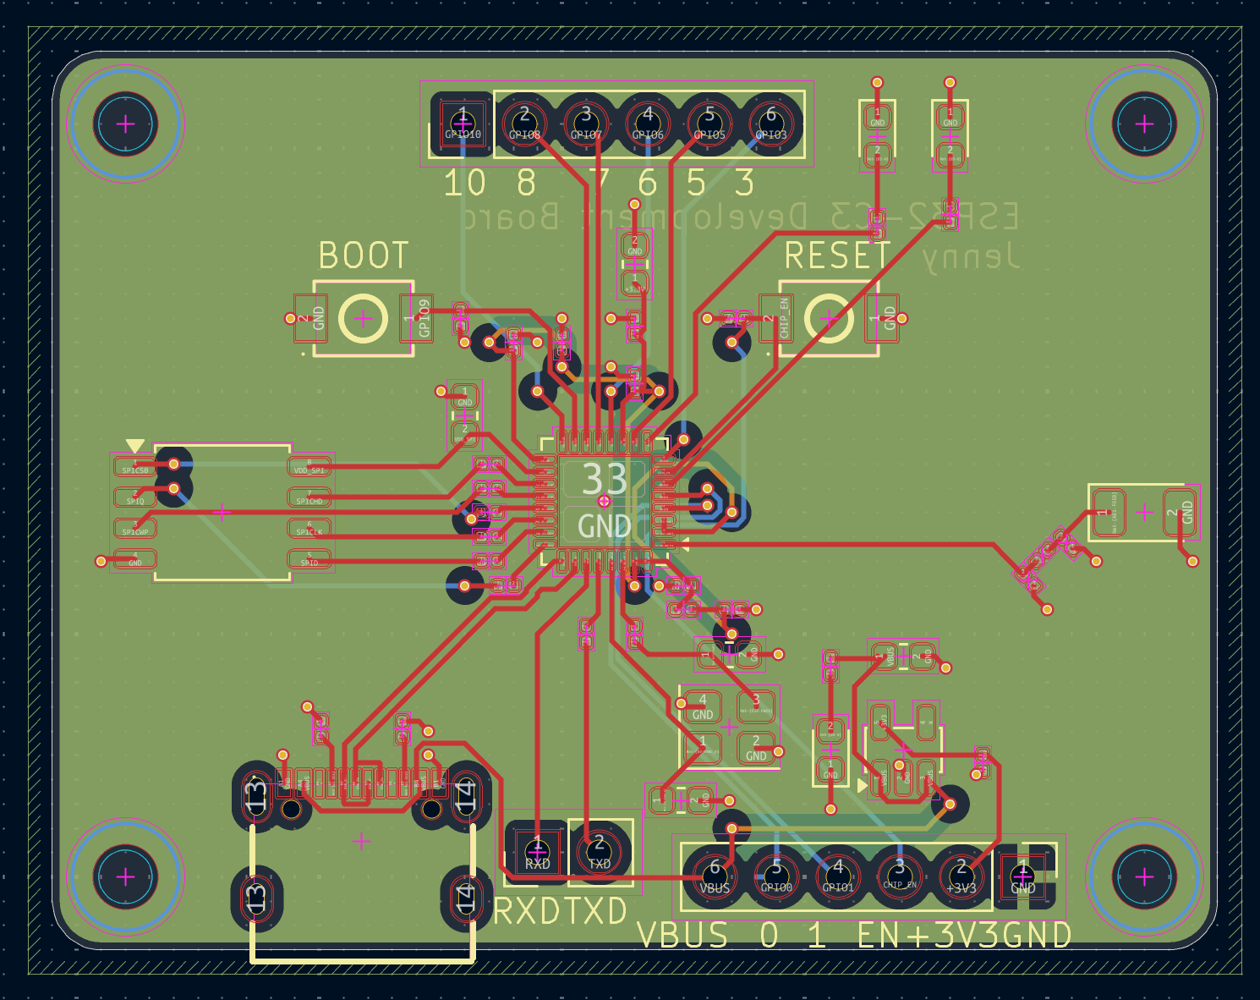
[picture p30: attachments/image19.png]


After relaying out my RF antenna I want to match 50 ohm impendence. Oh no my crystal has digital signals undernearth it! I now need to relocate the rf antenna yet again. oh crystal needs to be away from inductor oh ok

Moved the crystal slightly to the right out of the tracks way on the bottom. Ok now the layout is working. Now everything shoudld be working fine. Labels hard to read, I'll note down for the next time.

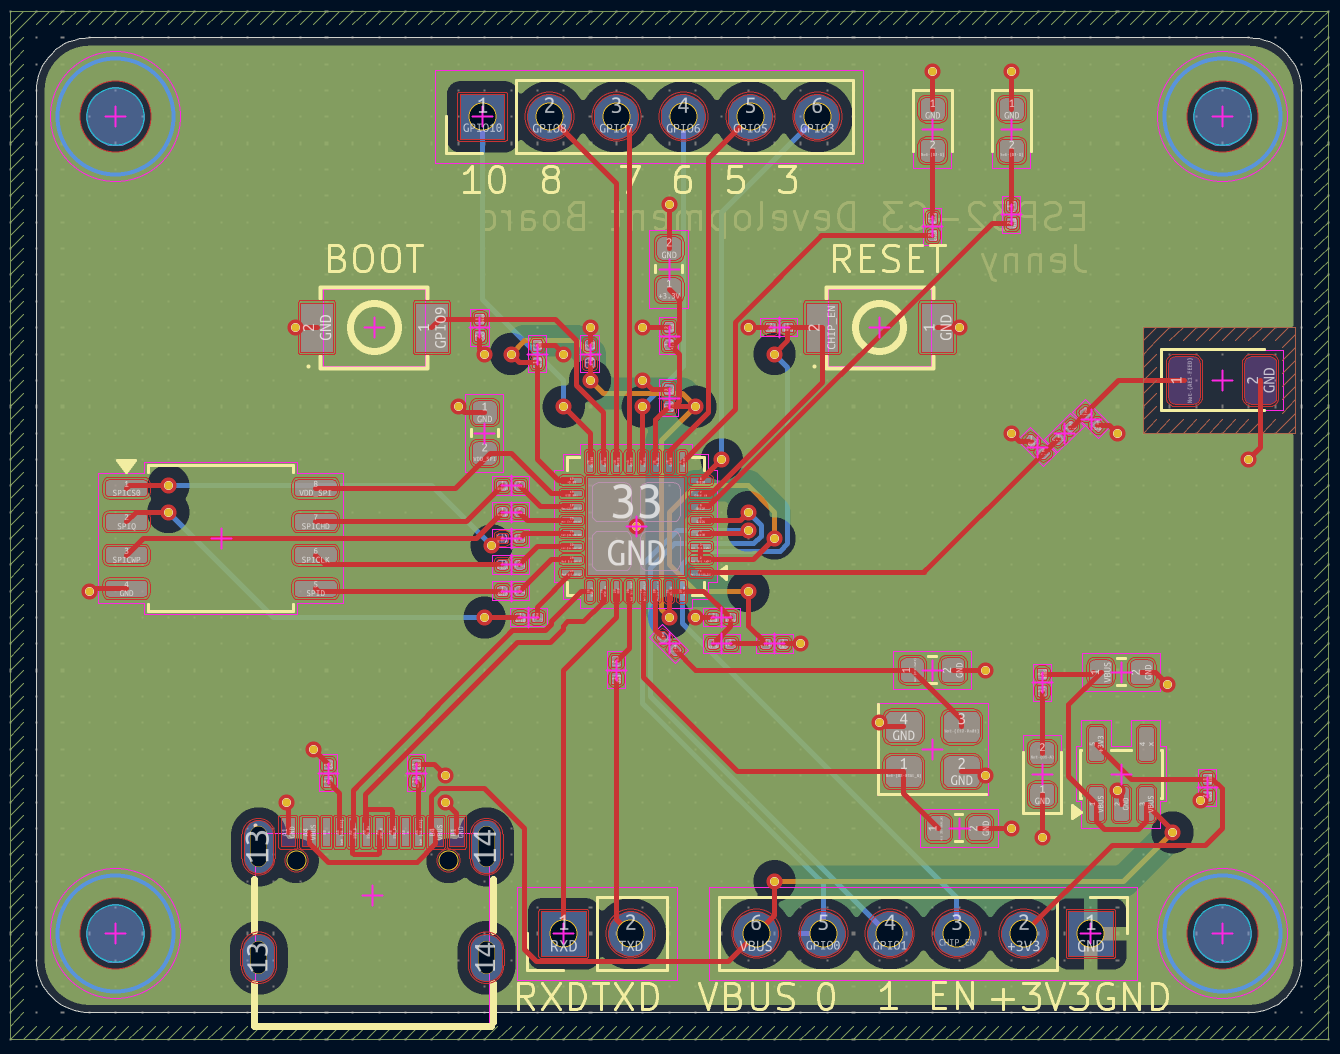
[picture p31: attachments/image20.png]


Now I focus on my impendence matching. I need to change stackup and convert some units. Ok changed my stackup mm and it is short and thin now. I'll round my values to whole numbers if i'm allowed to. Or I can keep this way it's fine.

Ok now I need to determine the values of the load for the RF antenna for RF tuning. Hmm I'll go with what I have because my design follows the PCB layout guide.

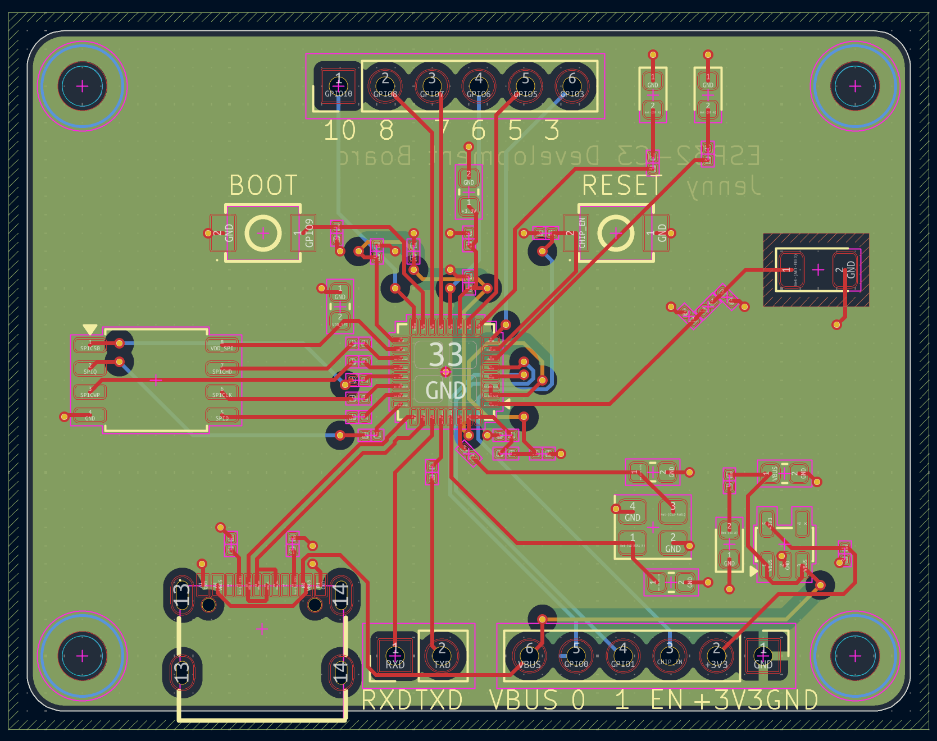
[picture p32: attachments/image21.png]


Now I need to find new LCSC parts. The capacitors I pick have high voltage just in case. BOM done. Need to reupload and update the README to repo.

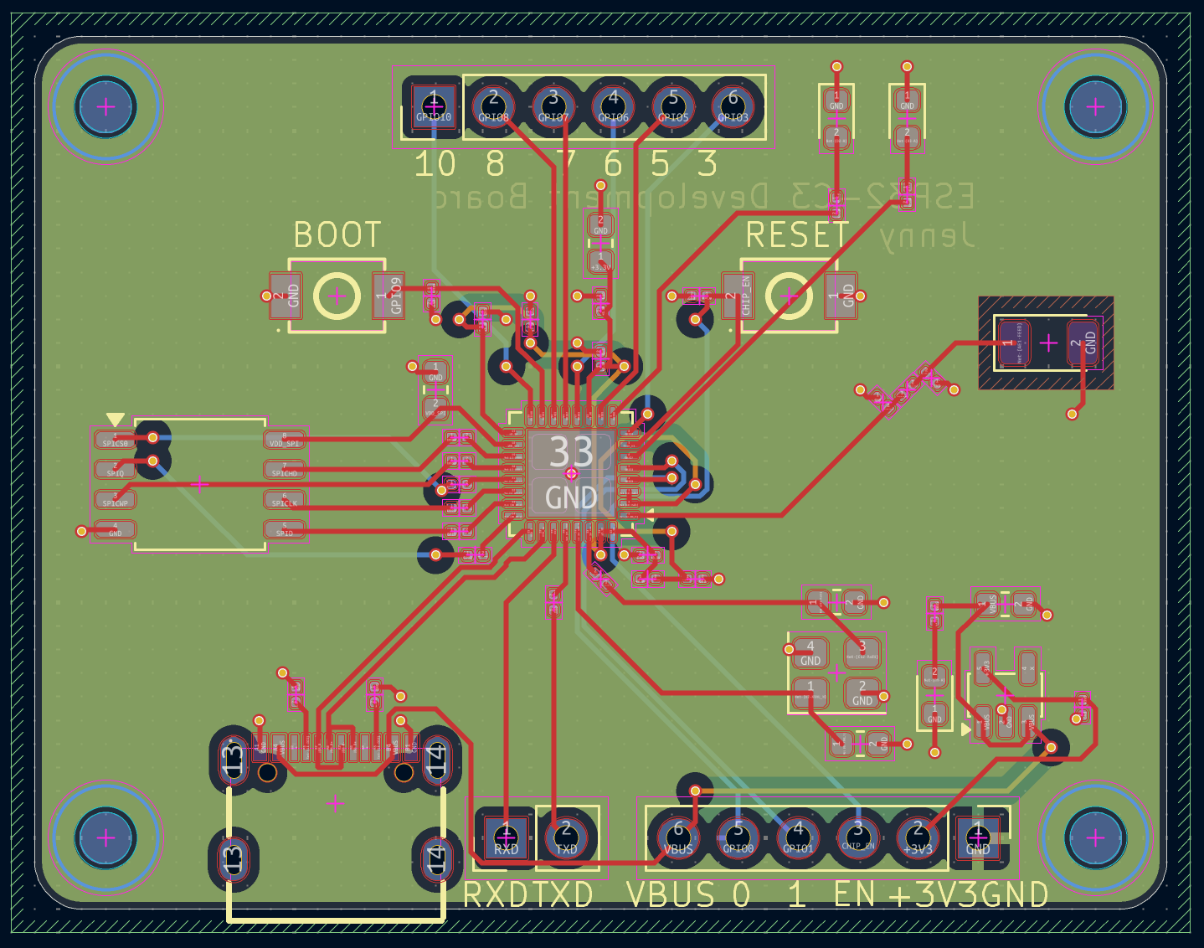
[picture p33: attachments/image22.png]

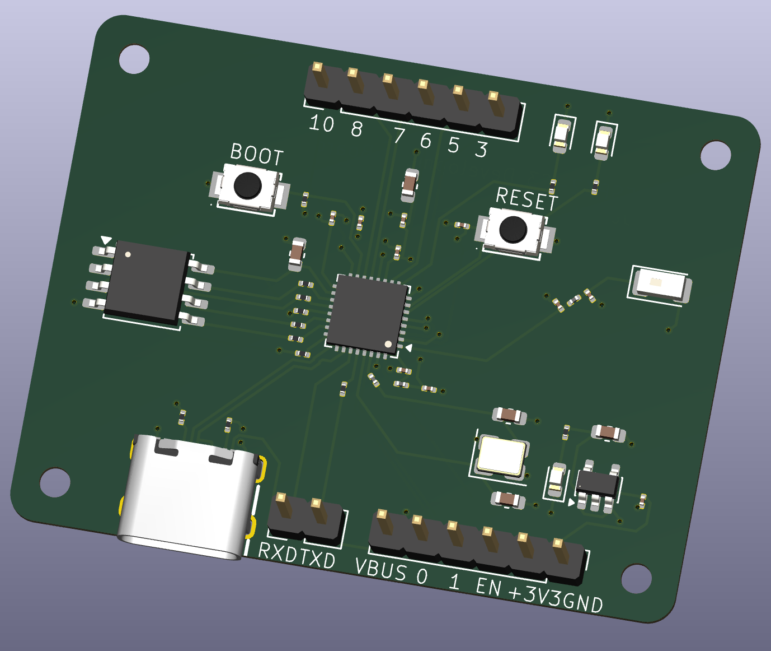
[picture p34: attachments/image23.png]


There are mistakes in here because I didn't update the footprint. Now it is correct since I changed it. Ran into technical issues bruh Fab toolkit won't export my files because of the 45 degrees. Guess I'll manually export then. Nvm I updated the plugin and now it works.

After some reviewing, my updated changes checklit include
- Move antenna to the edge on the side
- Change footprint from 0201 to 0402 to make it easier for myself except for the antenna
- maybe make the LDO capacitors big 0603 or 0805 because of many volts...
- new footprints means finding new part numbers yayy

Updated all the resistor footprints to 0603. Same for capacitors to 0402 except for 10uF. L1 and L2 updated to 0402. Ugh PCB to be wired again. Rework data lines that's crowded. All I did was rearrange it seems. I hope this is it. Also I stil need to find new part numbers... Capacitors ill bring in high tolerance and value just to be safe.

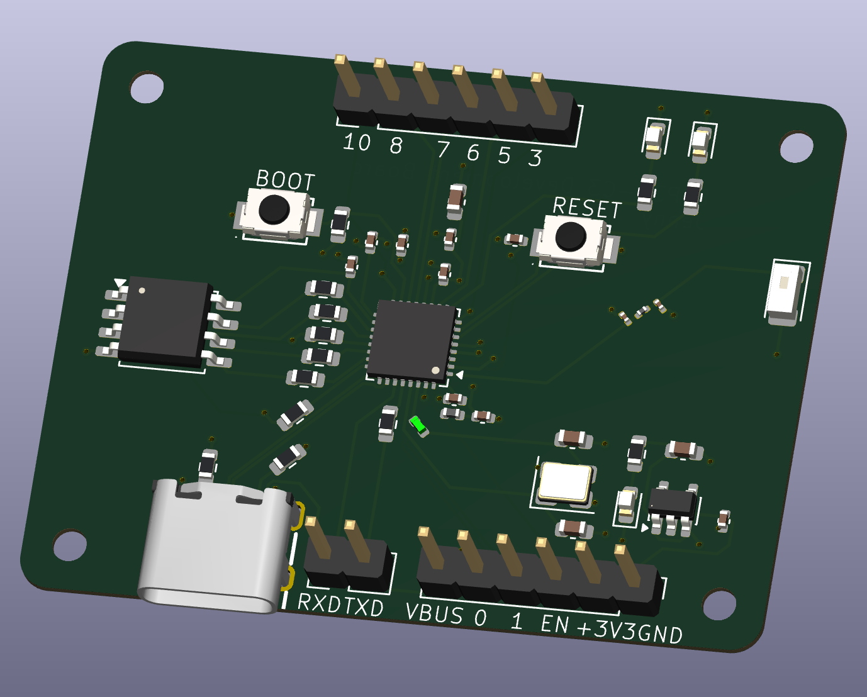
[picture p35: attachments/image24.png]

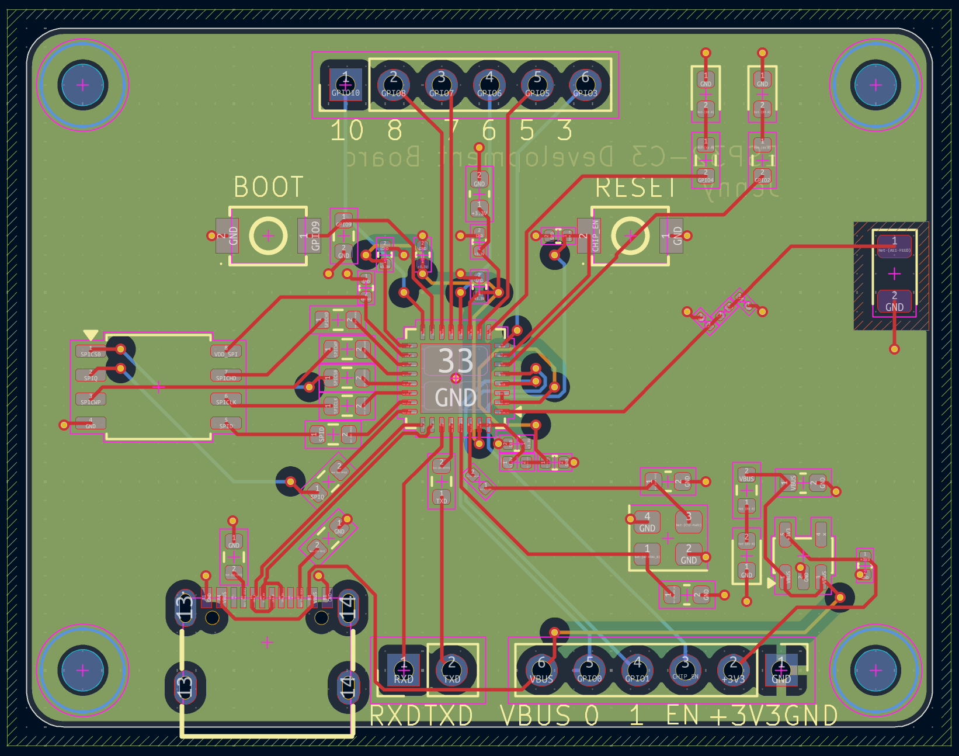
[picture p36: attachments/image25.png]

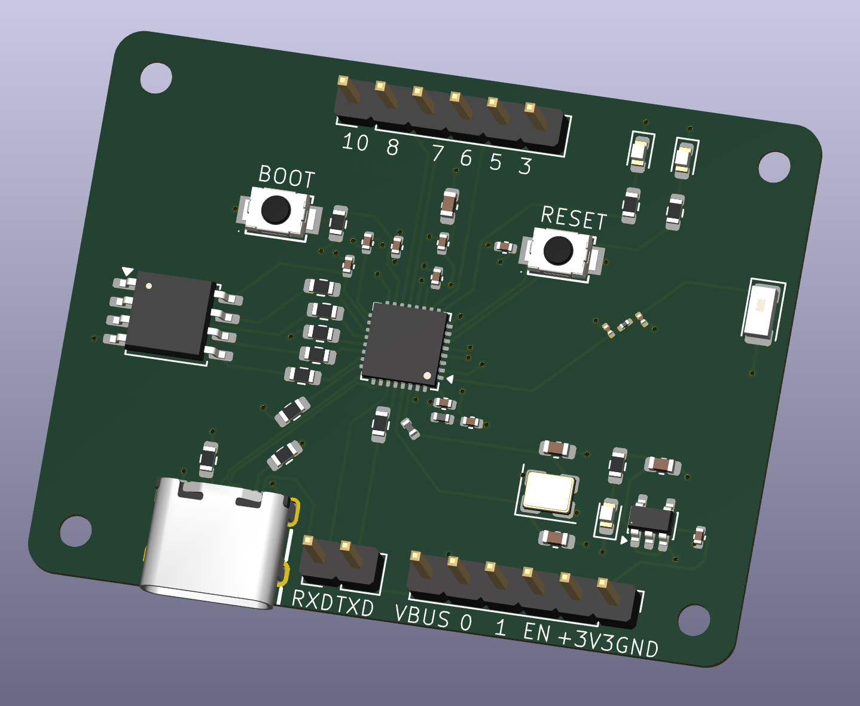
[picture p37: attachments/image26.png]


### Time Spent: 3 Hours

## May 23, 2026

Planned on changing the dimensions of a board to nice numbers and I might change my 4.7uF capacitor for LDO to a 0603 one. Have to redo my render and PCB image obviously. New dimensions 47 by 35. had to fit in the mounting holes tho. I still have space so im switching to 0603. Doing some final clean up. I wanna add more silkscreen somehow. Again I reupload my source code files too.

I want to find some cool silkscreen graphics I wonder what I can add... Well I don't have anything interesting so I won't add it for now.

### Time Spent: 0.5 hours

## May 25, 2026

More feedback
- incorrect load capacitor values
- pull down resistor for boot will bring to low state always

Ok i read my data sheet for the crystal it says 10pF or 20pF. What to pick. C stray is between 2pF and 5pF or 4pF to 6pF. I would go higher to minimize stray? yeah im picking 20pF. I'm guessing to subtract 6pF. Keeping 0603 footprint since it's ok and also I have space for it I think.
2(10-4) = 5pF
I'm going to change pull down to pull up but it means having to reroute it just a tiny bit!

### Time Spent: 0.5 Hours

Total time spent: Around 20 hours.

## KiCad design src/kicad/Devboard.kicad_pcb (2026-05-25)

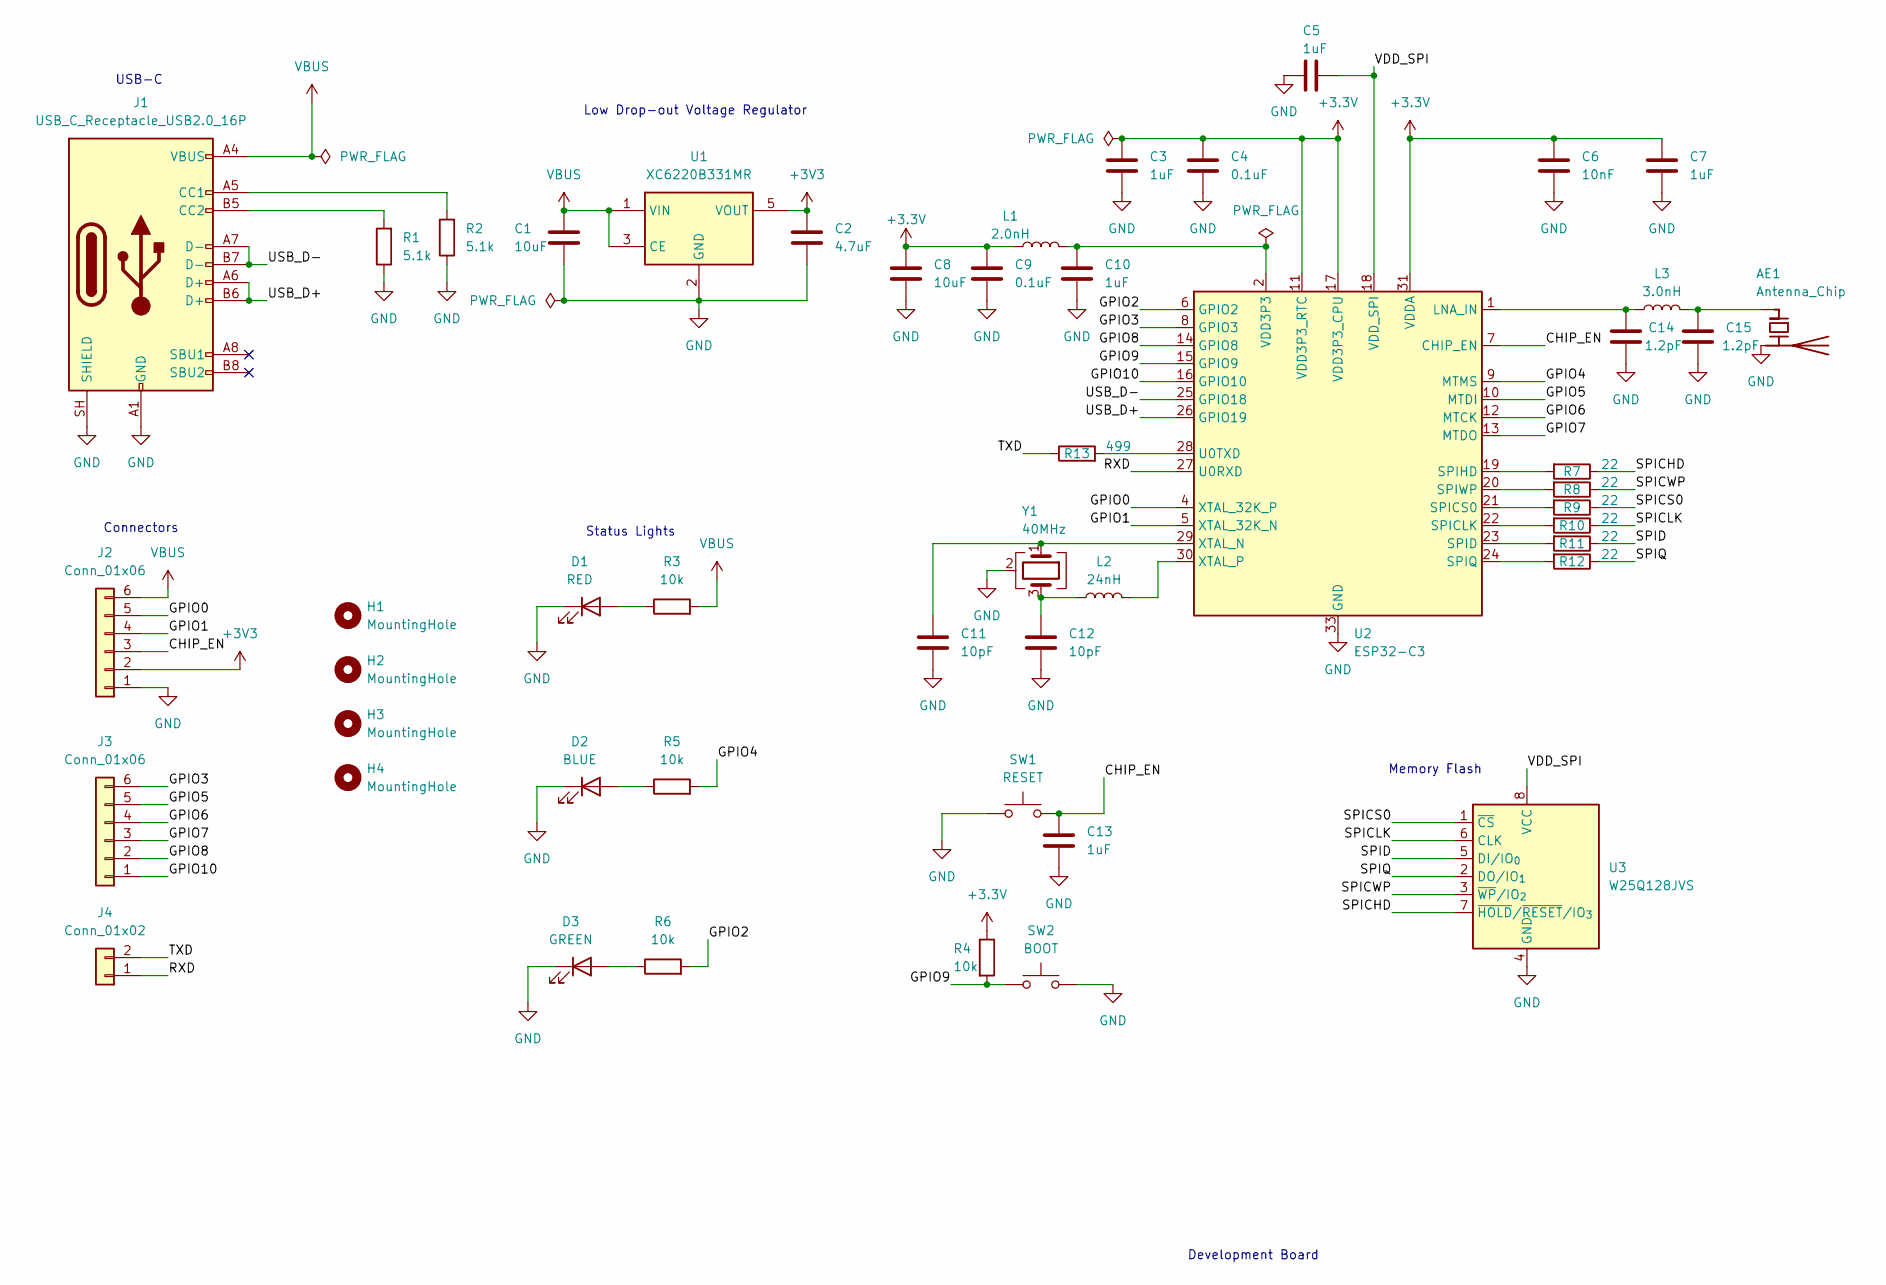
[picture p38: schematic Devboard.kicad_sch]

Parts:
AE1: Antenna_Chip; Johanson_2450AT18x100; LCSC Part C89334
C1, C8: 10uF; C_0603_1608Metric; LCSC Part C96446
C2: 4.7uF; C_0603_1608Metric; LCSC Part C69335
C3, C5, C7, C10, C13: 1uF; C_0402_1005Metric; LCSC Part C52923
C4, C9: 0.1uF; C_0402_1005Metric; LCSC Part C1525
C6: 10nF; C_0402_1005Metric; LCSC Part C15195
C11, C12: 10pF; C_0603_1608Metric; LCSC Part C1634
C14, C15: 1.2pF; C_0201_0603Metric; LCSC Part C85895
D1: RED; LED_0603_1608Metric; LCSC Part C19171390
D2: BLUE; LED_0603_1608Metric; LCSC Part C965807
D3: GREEN; LED_0603_1608Metric; LCSC Part C19273151
H1, H2, H3, H4: MountingHole; MountingHole_2.2mm_M2
J1: USB_C_Receptacle_USB2.0_16P; USB-C-SMD_TYPE-C-16PIN-2MD-073; LCSC Part C2765186
J2, J3: Conn_01x06; PinHeader_1x06_P2.54mm_Vertical
J4: Conn_01x02; PinHeader_1x02_P2.54mm_Vertical
L1: 2.0nH; L_0402_1005Metric; LCSC Part C18216
L2: 24nH; L_0402_1005Metric; LCSC Part C167472
L3: 3.0nH; L_0201_0603Metric; LCSC Part C98044
R1, R2: 5.1k; R_0603_1608Metric; LCSC Part C2907044
R3, R4, R5, R6: 10k; R_0603_1608Metric; LCSC Part C2930027
R7, R8, R9, R10, R11, R12: 22; R_0603_1608Metric; LCSC Part C2907129
R13: 499; R_0603_1608Metric; LCSC Part C23065
SW1: RESET; SW-SMD_L3.9-W3.0-P4.45; LCSC Part C720477
SW2: BOOT; SW-SMD_L3.9-W3.0-P4.45; LCSC Part C720477
U1: XC6220B331MR; SOT-23-5; LCSC Part C86534
U2: ESP32-C3; QFN-32-1EP_5x5mm_P0.5mm_EP3.7x3.7mm; LCSC Part C2838500
U3: W25Q128JVS; SOIC-8_5.3x5.3mm_P1.27mm; LCSC Part C97521
Y1: 40MHz; Crystal_SMD_3225-4Pin_3.2x2.5mm; LCSC Part C5444549

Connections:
+3.3V: C3.1, C4.1, C6.1, C7.1, C8.1, C9.1, L1.1, R4.1, U2.11 (VDD3P3_RTC), U2.17 (VDD3P3_CPU), U2.31 (VDDA), U2.32 (VDDA)
+3V3: C2.1, J2.2, U1.5 (VOUT)
/CHIP_EN: C13.1, J2.3, SW1.2, U2.7 (CHIP_EN)
/GPIO0: J2.5, U2.4 (XTAL_32K_P)
/GPIO1: J2.4, U2.5 (XTAL_32K_N)
/GPIO2: R6.2, U2.6 (GPIO2)
/GPIO3: J3.6, U2.8 (GPIO3)
/GPIO4: R5.2, U2.9 (MTMS)
/GPIO5: J3.5, U2.10 (MTDI)
/GPIO6: J3.4, U2.12 (MTCK)
/GPIO7: J3.3, U2.13 (MTDO)
/GPIO8: J3.2, U2.14 (GPIO8)
/GPIO9: R4.2, SW2.1, U2.15 (GPIO9)
/GPIO10: J3.1, U2.16 (GPIO10)
/RXD: J4.1, U2.27 (U0RXD)
/SPICHD: R7.1, U3.7 (~HOLD/~RESET/IO_{3})
/SPICLK: R10.1, U3.6 (CLK)
/SPICS0: R9.1, U3.1 (~CS)
/SPICWP: R8.1, U3.3 (~WP/IO_{2})
/SPID: R11.1, U3.5 (DI/IO_{0})
/SPIQ: R12.1, U3.2 (DO/IO_{1})
/TXD: J4.2, R13.1
/USB_D+: J1.A6 (D+), J1.B6 (D+), U2.26 (GPIO19)
/USB_D-: J1.A7 (D-), J1.B7 (D-), U2.25 (GPIO18)
/VDD_SPI: C5.2, U2.18 (VDD_SPI), U3.8 (VCC)
GND: AE1.2 (PCB_Trace), C1.2, C2.2, C3.2, C4.2, C5.1, C6.2, C7.2, C8.2, C9.2, C10.2, C11.2, C12.2, C13.2, C14.1, C15.1, D1.1 (K), D2.1 (K), D3.1 (K), J1.A1 (GND), J1.A12 (GND), J1.B1 (GND), J1.B12 (GND), J1.SH (SHIELD), J2.1, R1.1, R2.1, SW1.1, SW2.2, U1.2 (GND), U2.33 (GND), U3.4 (GND), Y1.2 (G), Y1.4 (G)
unnamed: AE1.1 (FEED), C15.2, L3.2
unnamed: C10.1, L1.2, U2.2 (VDD3P3), U2.3 (VDD3P3)
unnamed: C12.1, L2.1, Y1.3
unnamed: D1.2 (A), R3.1
unnamed: D2.2 (A), R5.1
unnamed: D3.2 (A), R6.1
unnamed: J1.A5 (CC1), R2.2
unnamed: J1.B5 (CC2), R1.2
unnamed: C14.2, L3.1, U2.1 (LNA_IN)
unnamed: R10.2, U2.22 (SPICLK)
unnamed: R9.2, U2.21 (SPICS0)
unnamed: R11.2, U2.23 (SPID)
unnamed: R7.2, U2.19 (SPIHD)
unnamed: R12.2, U2.24 (SPIQ)
unnamed: R8.2, U2.20 (SPIWP)
unnamed: R13.2, U2.28 (U0TXD)
unnamed: C11.1, U2.29 (XTAL_N), Y1.1
unnamed: L2.2, U2.30 (XTAL_P)
VBUS: C1.1, J1.A4 (VBUS), J1.A9 (VBUS), J1.B4 (VBUS), J1.B9 (VBUS), J2.6, R3.2, U1.1 (VIN), U1.3 (CE)

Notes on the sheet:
Low Drop-out Voltage Regulator
USB-C
Connectors
Development Board
Memory Flash
Status Lights

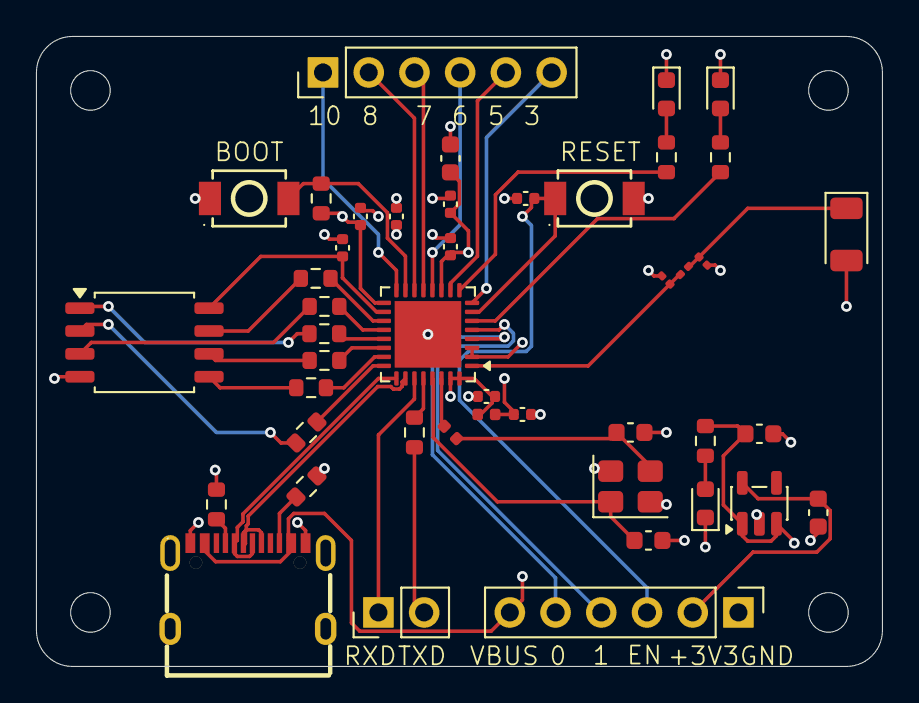
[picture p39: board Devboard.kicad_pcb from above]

Board: 4 copper layers, 47.0 x 35.0 mm, 49 parts (0 on the bottom side), 45 nets.

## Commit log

2026-05-20 Update project
    [Devboard.kicad_pcb, Devboard.kicad_sch, bom.csv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]
2026-05-23 Update Journal
    [Devboard.kicad_pcb, Devboard.kicad_sch, bom.csv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]
2026-05-23 Update Journal after review
    [Devboard.kicad_pcb, Devboard.kicad_sch, bom.csv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]
2026-05-26 Add case
    [3D.step, case.step, case_bottom.stl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]
2026-07-14 Update BOM
    [bom.csv]
